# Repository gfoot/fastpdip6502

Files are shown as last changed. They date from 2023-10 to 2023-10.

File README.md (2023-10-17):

# Fast PDIP 6502 project sources

This is my attempt at making a fast 6502-based computer, overclocking the CPU to 32MHz and 
beyond, while retaining a 70s/80s-style parallel architecture, with ISA-style expansion slots,
using only PDIP and through-hole components.

See https://hackaday.io/project/192630-fast-pdip-6502-computer for more details including
photos, schematics, and a more complete description of the development and theory of the
project.

This repository contains:

* hardware/breadboard - schematics and "PCB" layout files for the breadboard prototype
* hardware/pcb - schematics, PCB layouts, gerbers, etc for the all the PCBs
* pld - various PLD module code required by different versions
* server - Python serial server code
* src - 6502 assembler code
* utils - other utility scripts

See also other READMEs:
* [src/README.md](src/README.md)
* [hardware/pcb/README.md](hardware/pcb/README.md)
* [hardware/breadboard/README.md](hardware/breadboard/README.md)

# Building

The hardware files need to be loaded into KiCad 7.0 for editing, exporting gerbers, etc.

The gerber zips can be sent straight to a PCB manufacturer if you just want the same PCBs that
I am using.

The PLD files are built using WinCupl.  I do this from the command line but you can also do it
in the GUI if you prefer.

The 6502 assembler source is built using xa, which is easy to install under Ubuntu at least.  One build
step requires use of Python to create a #include file - I use Python 3 for this.  There's a Makefile in
the "src" directory.

The serial server program is also written in Python, for Python 3.

All of this is run on Ubuntu Linux but you should be able to port it to other systems.

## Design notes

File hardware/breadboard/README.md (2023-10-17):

# Breadboard circuit and layout

This project was used to define a slightly modified circuit for implementation on solderless
breadboards, and to plan the layout of the components.  It combines the CPU and I/O modules, but has
some parts removed which are only relevant to the PCB version such as I/O expansion sockets.

The PCB layout editor shows the positioning of the components on the breadboard, but not the connections between them.

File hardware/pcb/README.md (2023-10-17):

# PCB design files

There are various KiCad projects that together make up the system.  The I/O module and CPU module are required
of course, the others are optional add-ons.

The gerbers for all the revisions I've made ("issues") are also included, along with exported schematics in PDF and PNG files
correspsonding to those revisions for easy reference.

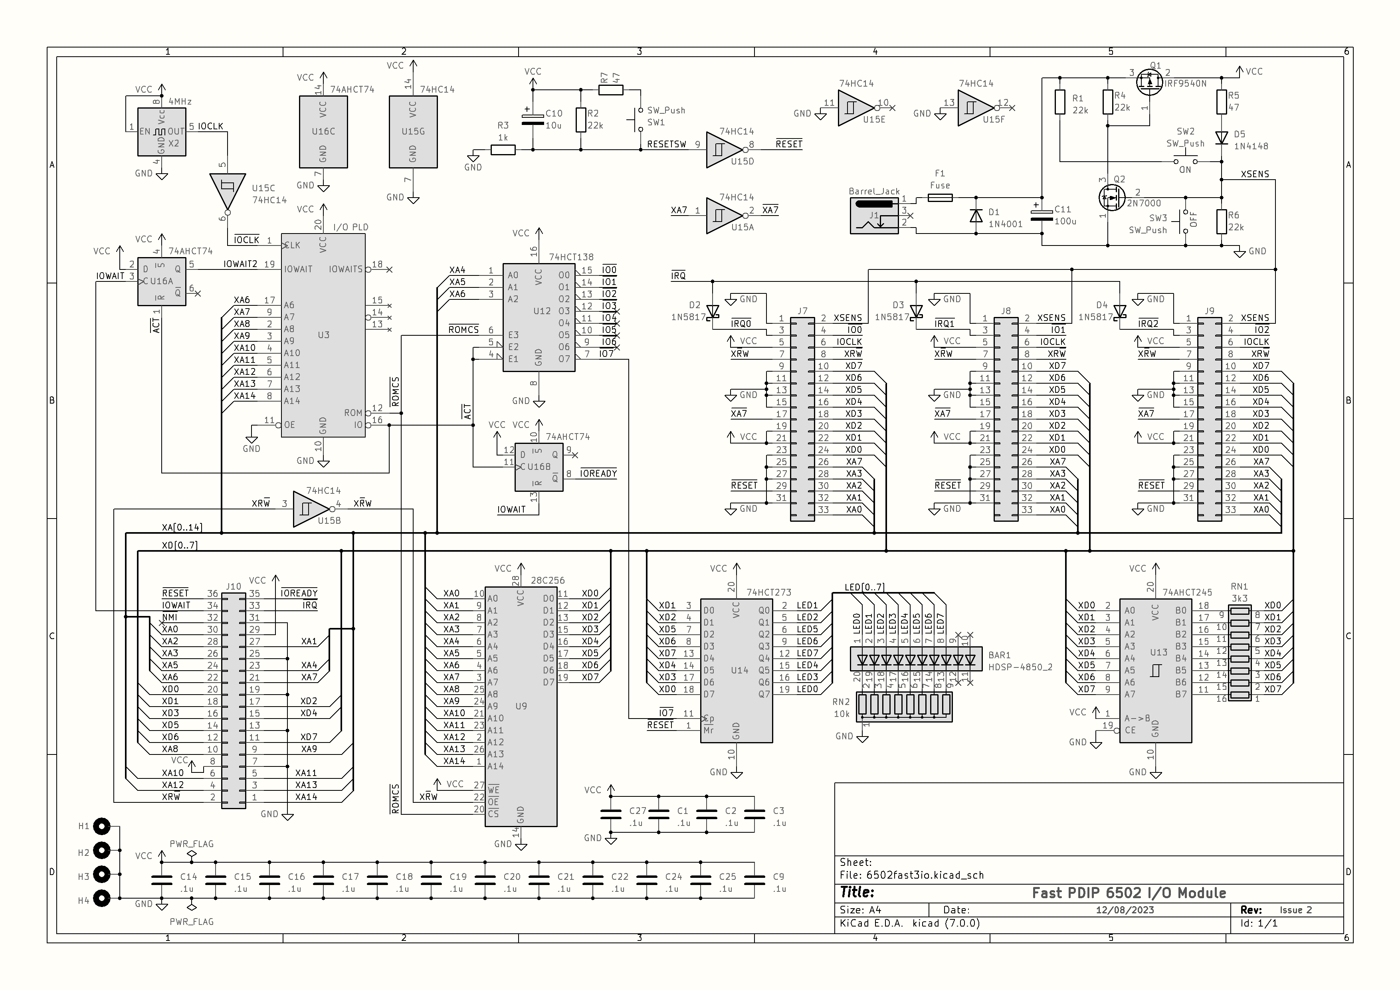
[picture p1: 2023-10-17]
hardware/pcb/schematics/6502fast3io-iss2-schematic.png

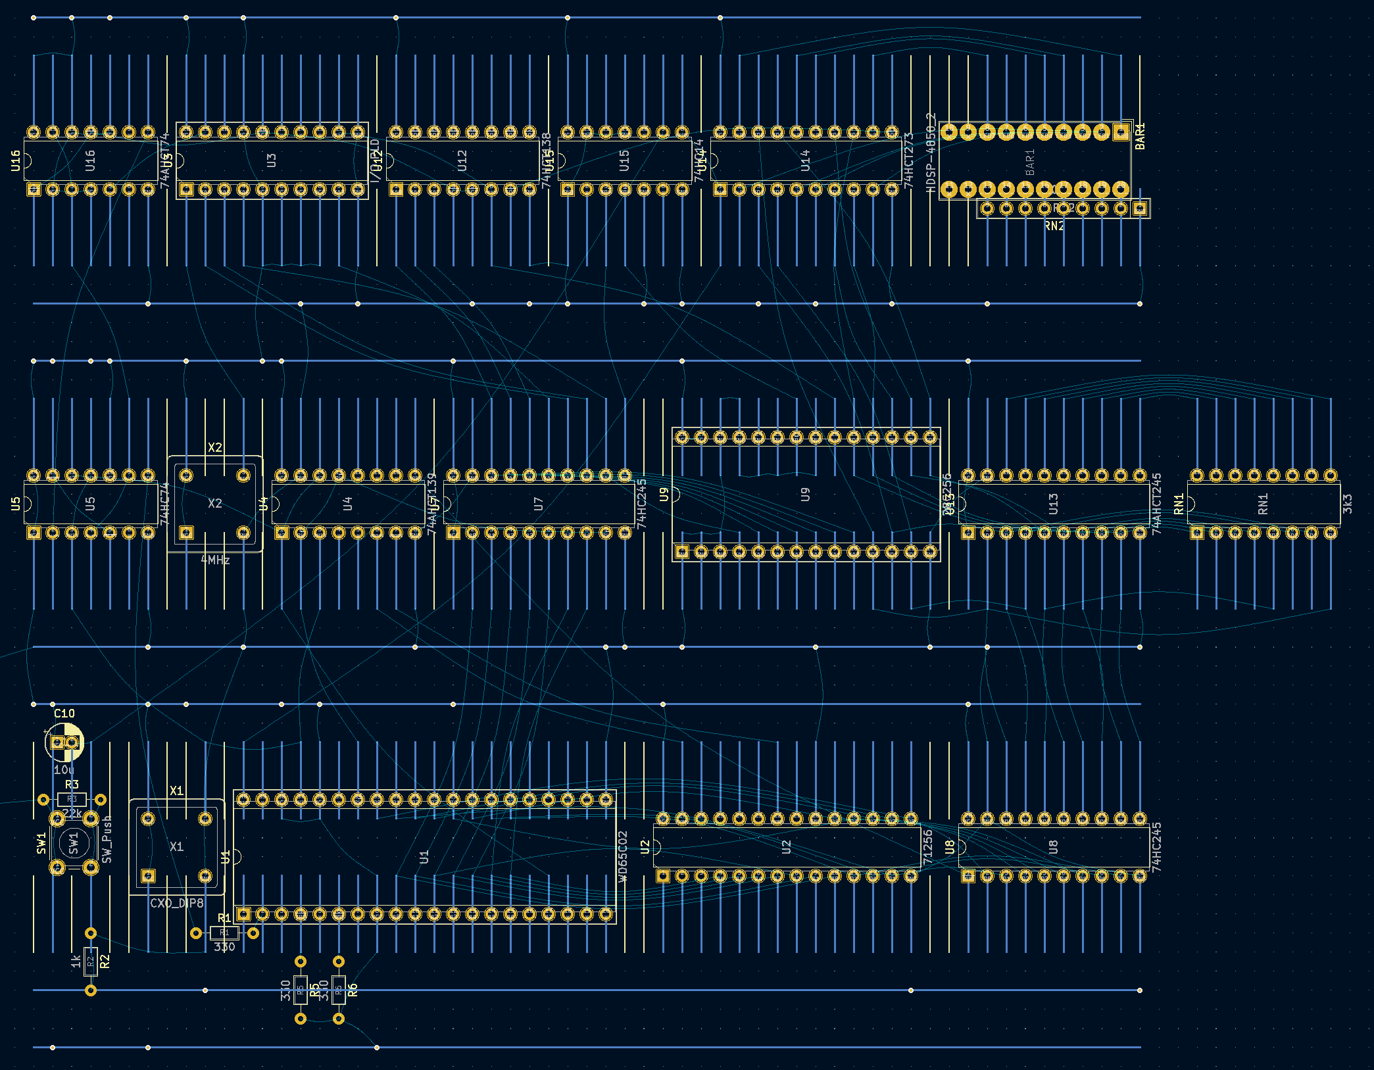
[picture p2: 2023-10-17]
hardware/breadboard/6502fastbb/kicad-breadboard-layout.png

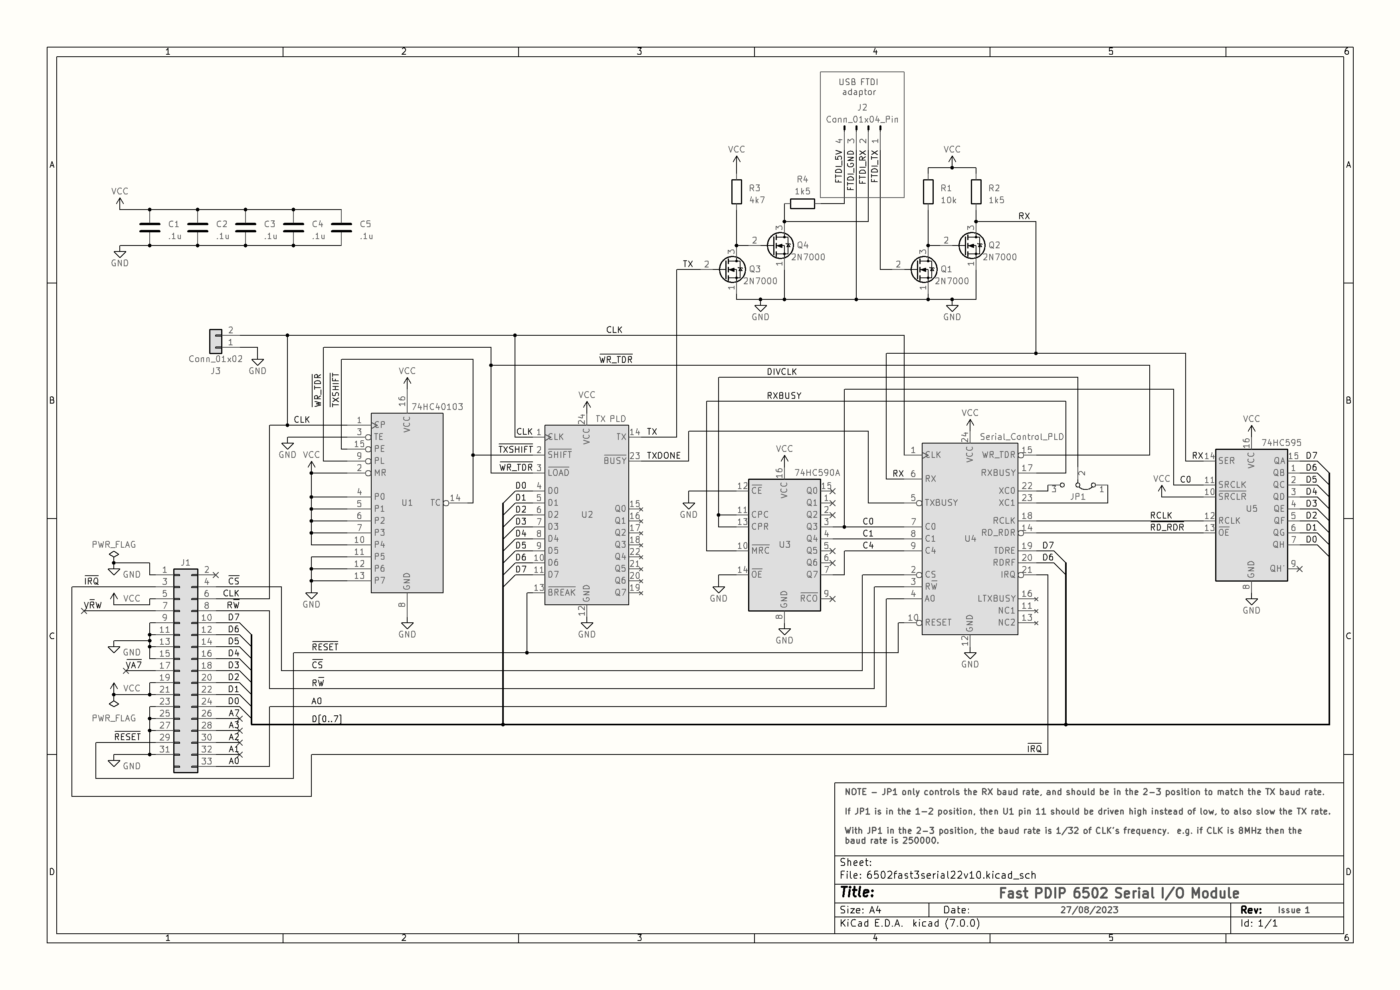
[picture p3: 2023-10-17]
hardware/pcb/schematics/6502fast3serial22v10-iss1-schematic.png

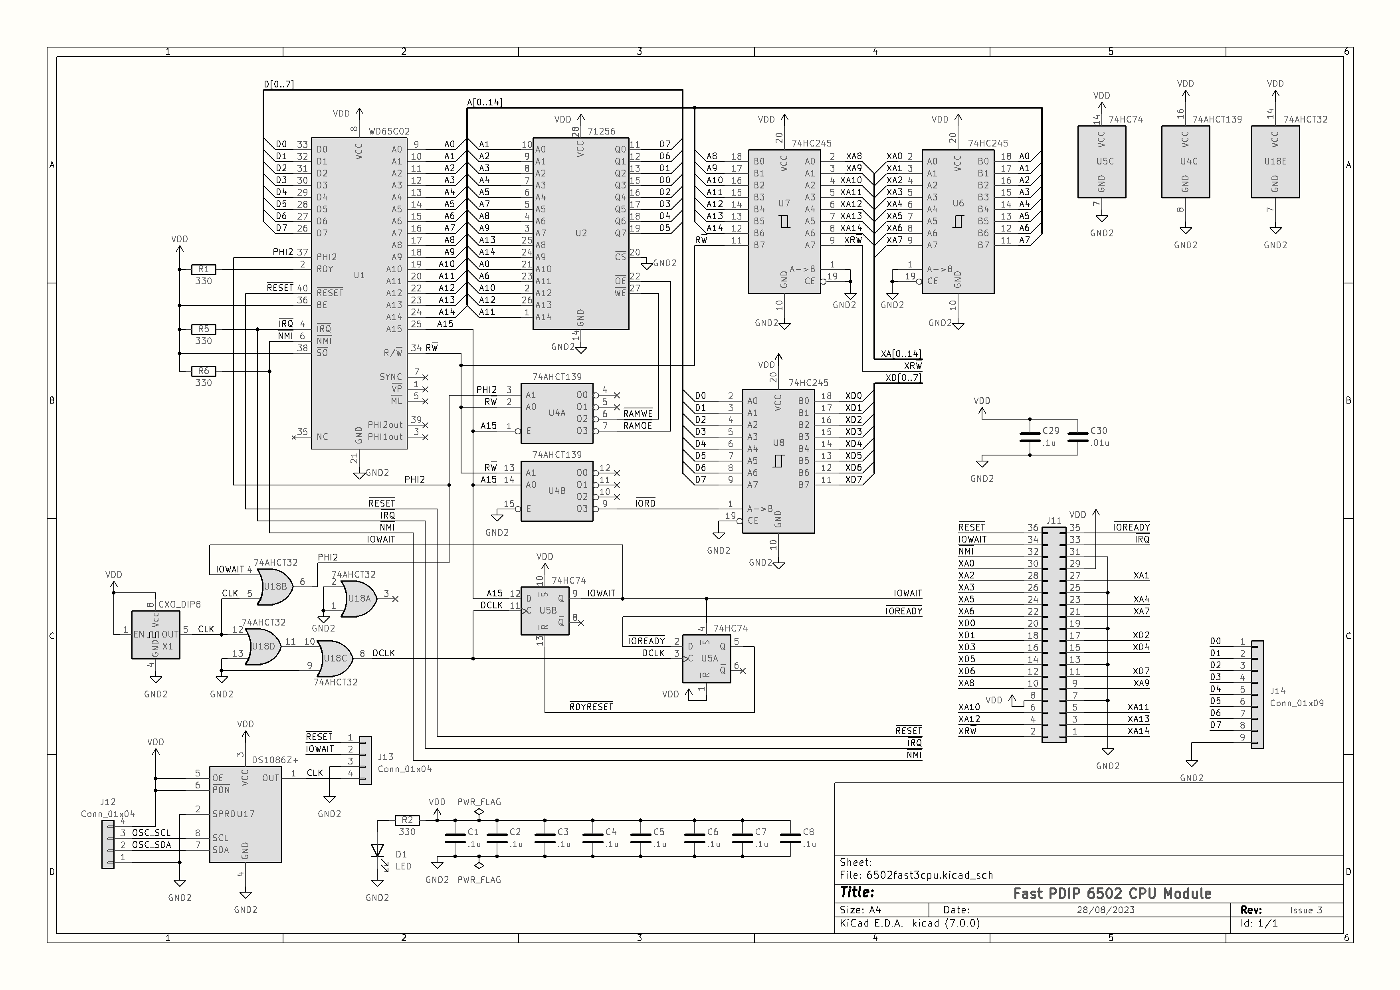
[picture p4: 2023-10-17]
hardware/pcb/schematics/6502fast3cpu-iss3-schematic.png

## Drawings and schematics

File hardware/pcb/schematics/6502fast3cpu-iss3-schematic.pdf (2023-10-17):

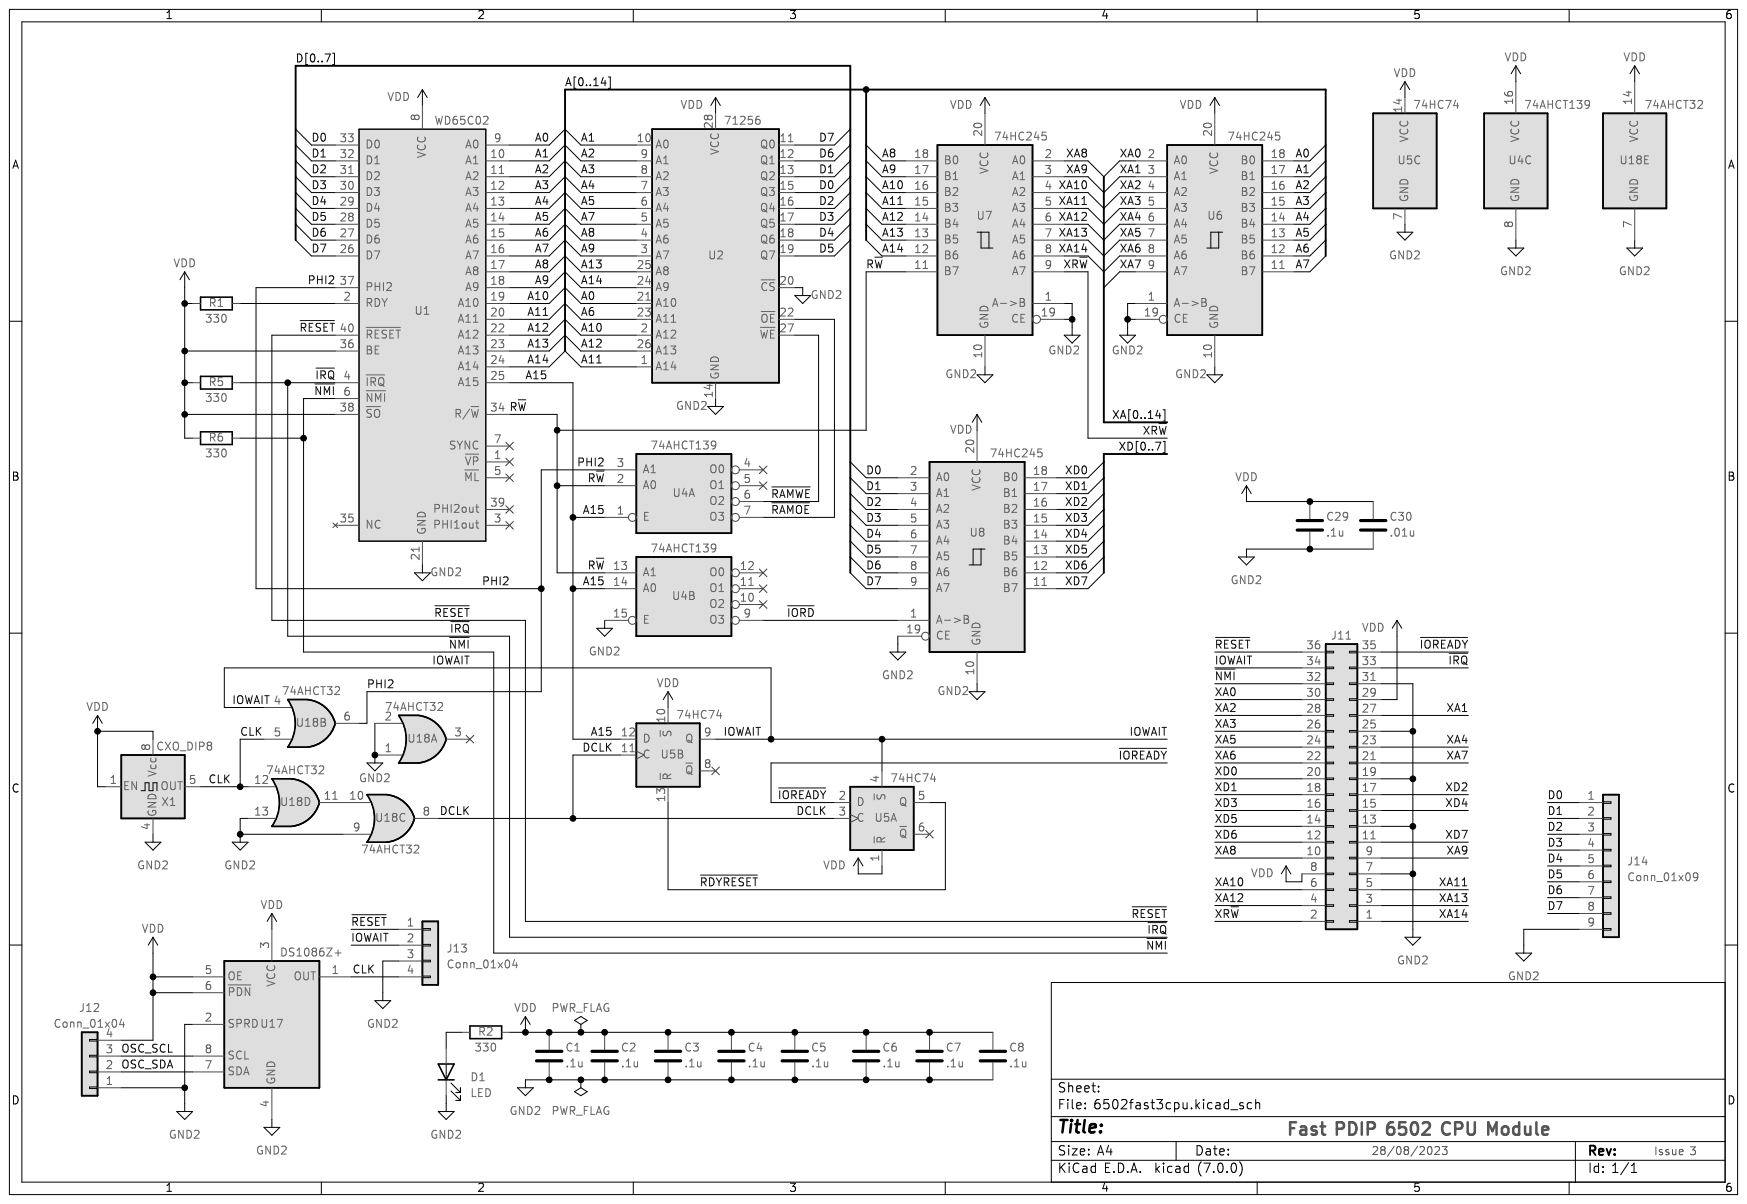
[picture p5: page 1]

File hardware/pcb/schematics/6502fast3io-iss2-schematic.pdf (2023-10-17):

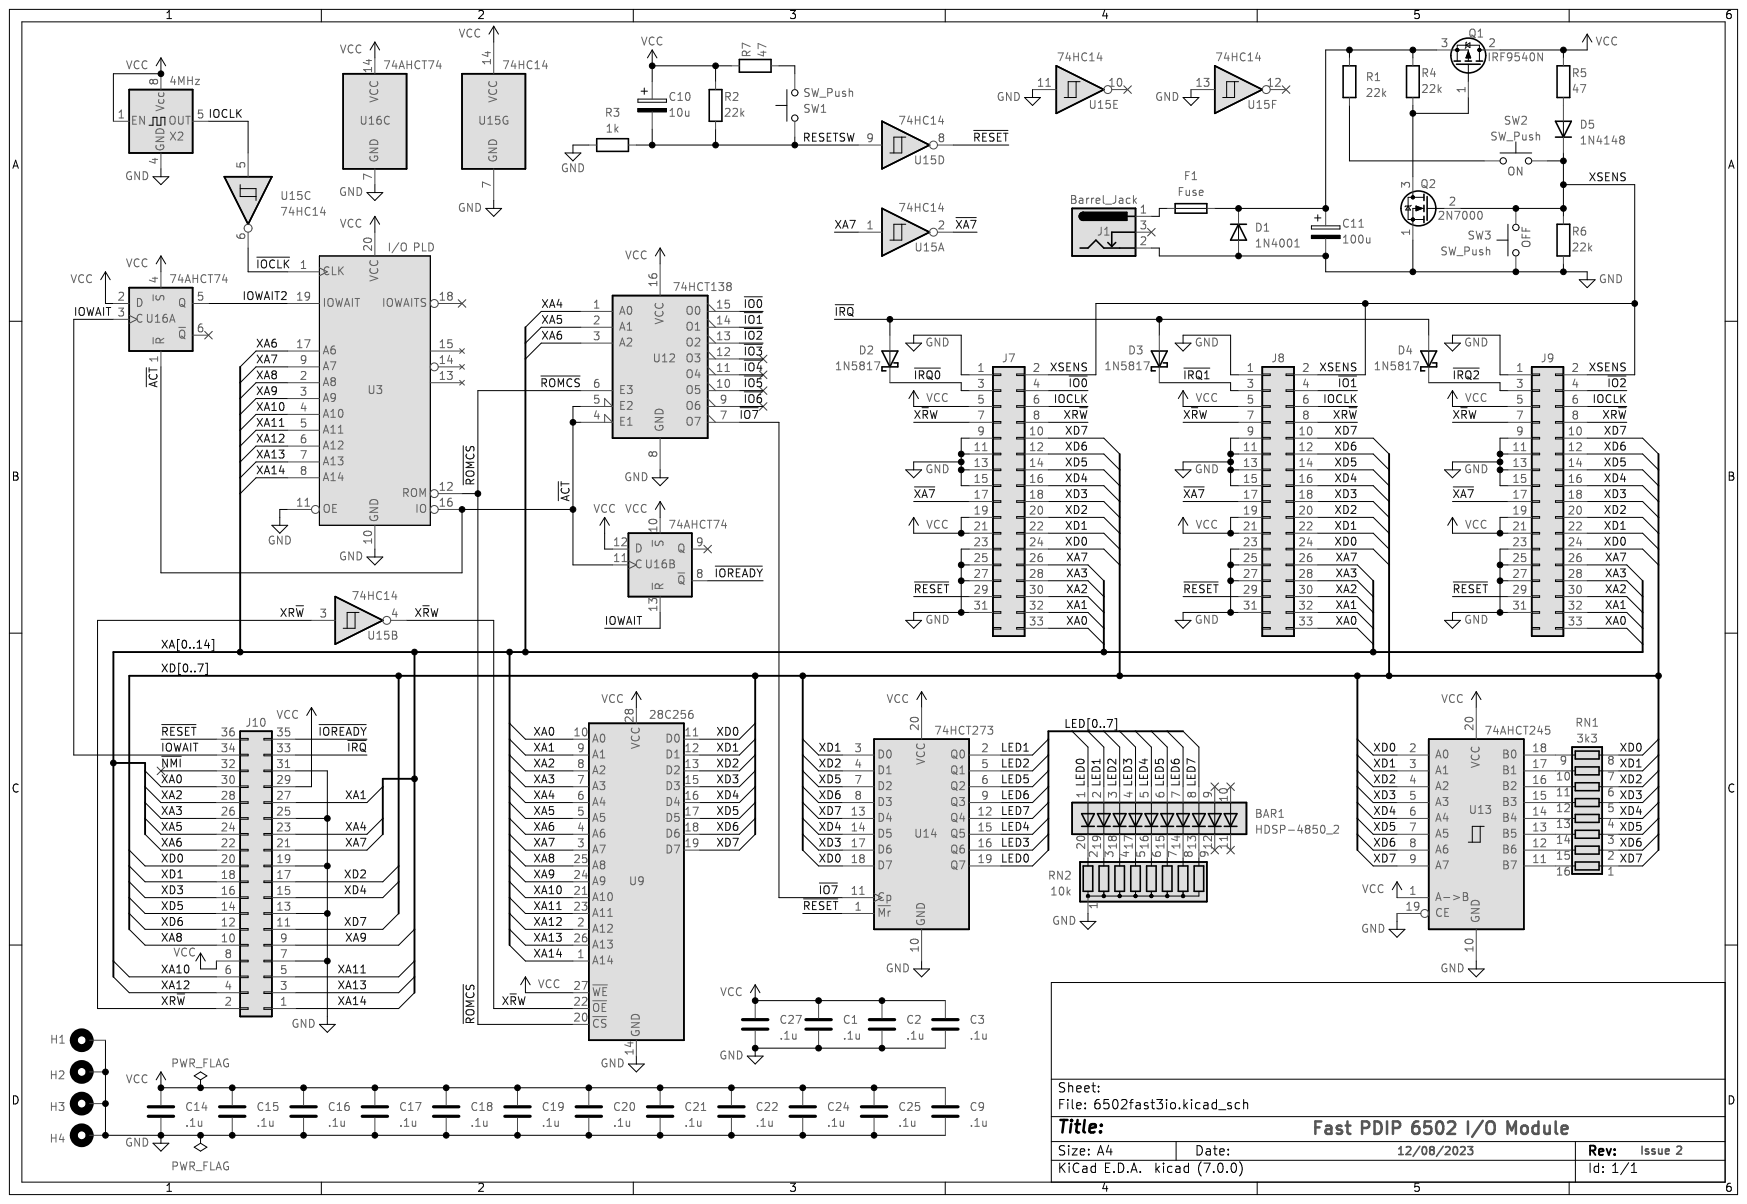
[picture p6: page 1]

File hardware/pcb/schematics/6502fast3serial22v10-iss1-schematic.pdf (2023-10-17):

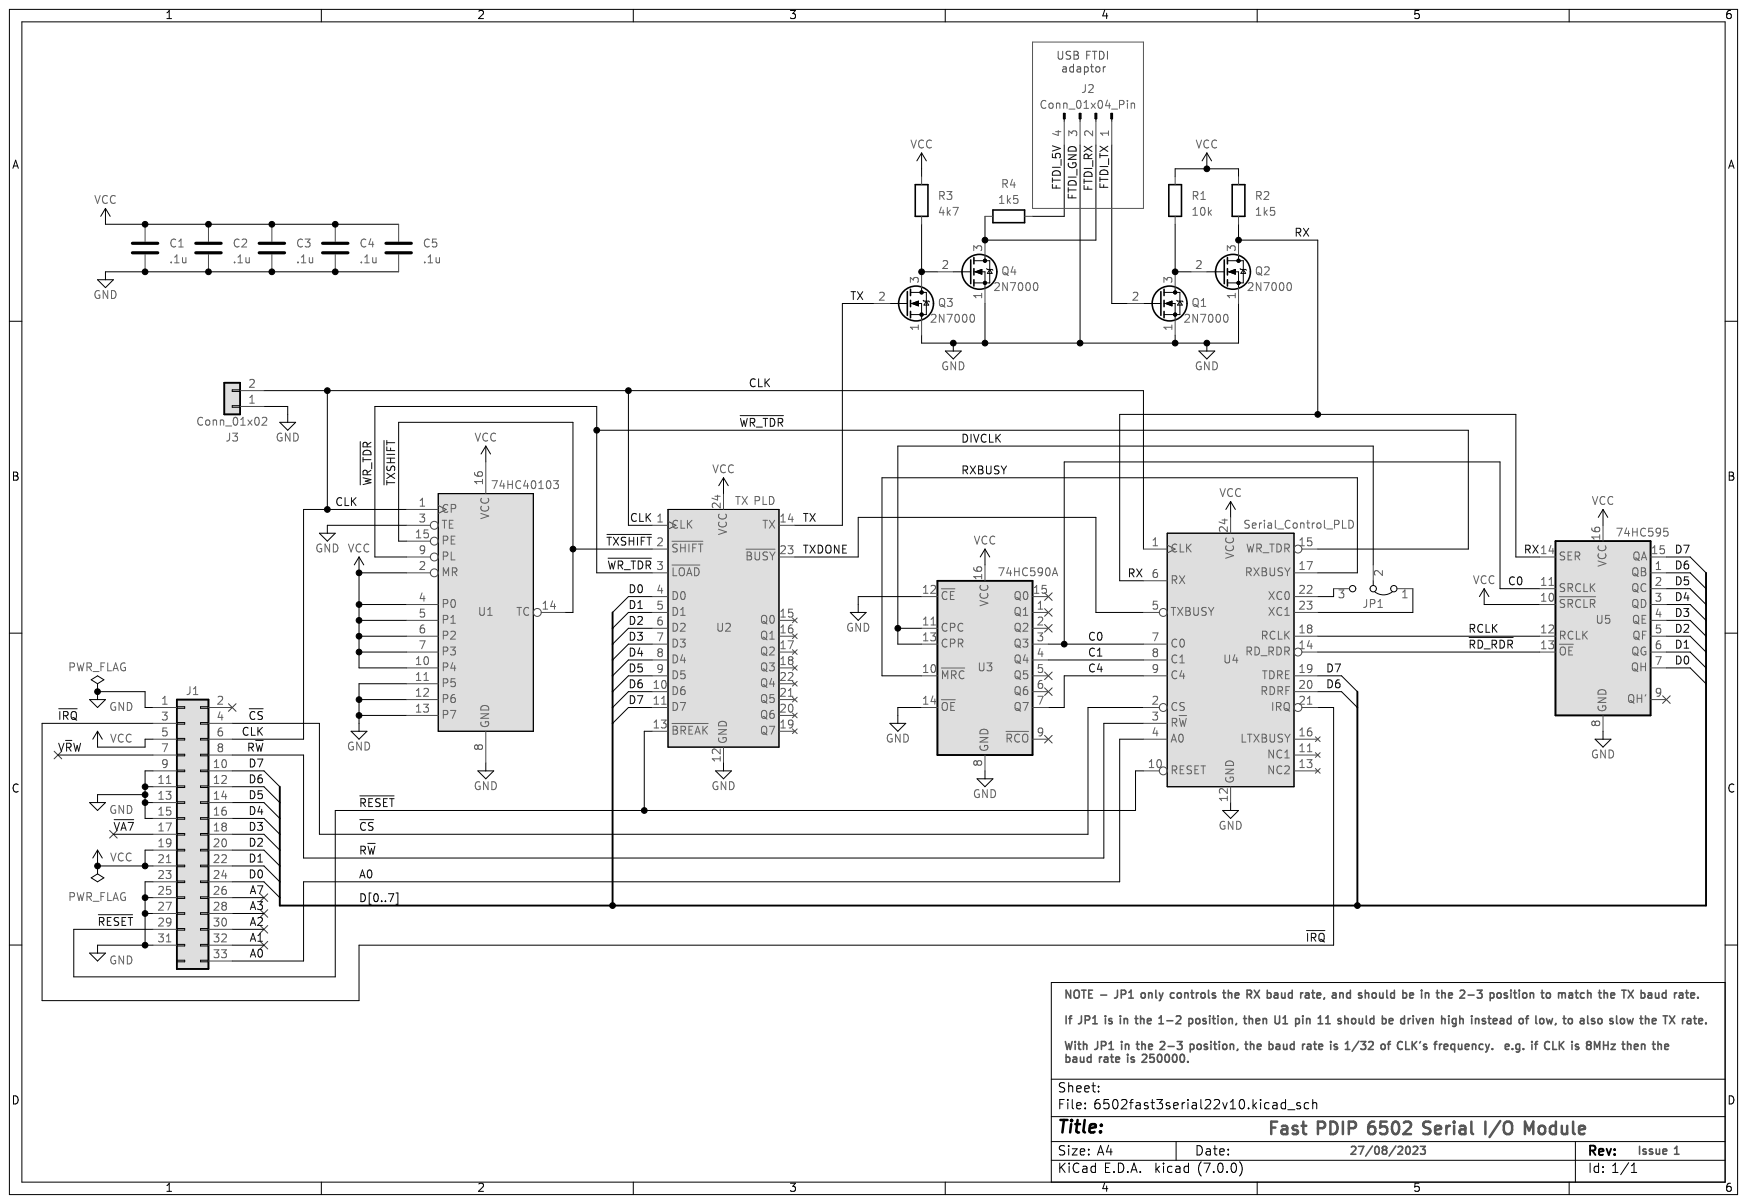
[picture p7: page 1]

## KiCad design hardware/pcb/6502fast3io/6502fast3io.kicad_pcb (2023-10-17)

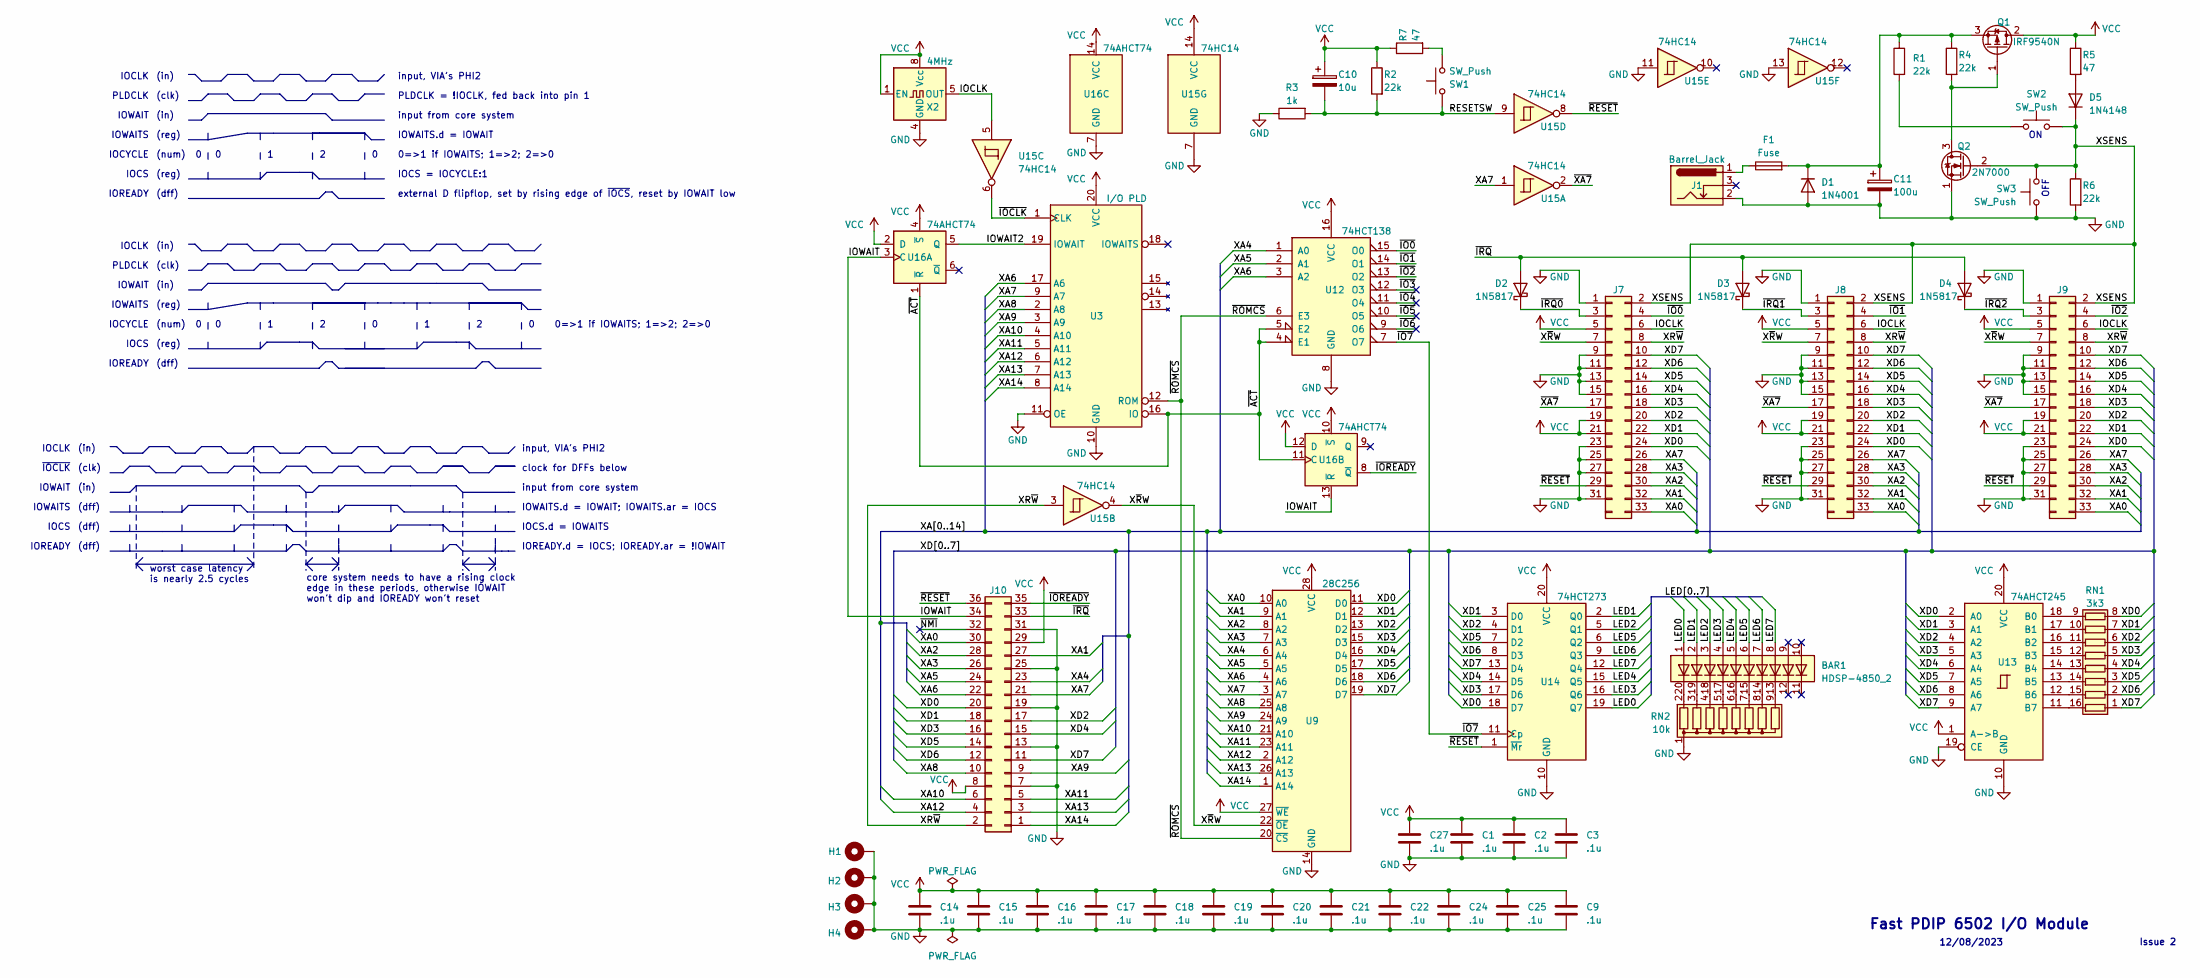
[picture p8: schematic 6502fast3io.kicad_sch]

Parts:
BAR1: HDSP-4850_2; HDSP-4850
C1, C2, C3, C9, C14, C15, C16, C17, C18, C19, C20, C21, C22, C24, C25, C27: .1u; C_Disc_D3.0mm_W1.6mm_P2.50mm
C10: 10u; CP_Radial_D5.0mm_P2.00mm
C11: 100u; CP_Radial_D5.0mm_P2.00mm
D1: 1N4001; D_DO-41_SOD81_P10.16mm_Horizontal
D2, D3, D4: 1N5817; D_DO-34_SOD68_P7.62mm_Horizontal
D5: 1N4148; D_DO-34_SOD68_P10.16mm_Horizontal
F1: Fuse; R_Axial_DIN0207_L6.3mm_D2.5mm_P10.16mm_Horizontal
H1, H2, H3, H4: MountingHole_Pad; MountingHole_2.2mm_M2_Pad
J1: Barrel_Jack; BarrelJack_Horizontal
J7, J8, J9: conn_pcb_edge_33pin_sense; 6502fast2_IO_PCBEdgeSocket
J10: Conn_02x18_Odd_Even; PCB_Edge_Socket_36pin
Q1: IRF9540N; TO-220-3_Horizontal_TabDown_NoHole
Q2: 2N7000; TO-92_Inline
R1, R2, R4, R6: 22k; R_Axial_DIN0204_L3.6mm_D1.6mm_P7.62mm_Horizontal
R3: 1k; R_Axial_DIN0204_L3.6mm_D1.6mm_P7.62mm_Horizontal
R5, R7: 47; R_Axial_DIN0204_L3.6mm_D1.6mm_P7.62mm_Horizontal
RN1: 3k3; DIP-16_W7.62mm
RN2: 10k; R_Array_SIP9
SW1, SW2, SW3: SW_Push; SW_PUSH_6mm_H4.3mm
U3: I/O PLD; DIP-20_W7.62mm_Socket
U9: 28C256; DIP-28_W15.24mm_Socket
U12: 74HCT138; DIP-16_W7.62mm
U13: 74AHCT245; DIP-20_W7.62mm
U14: 74HCT273; DIP-20_W7.62mm
U15: 74HC14; DIP-14_W7.62mm
U16: 74AHCT74; DIP-14_W7.62mm
X2: 4MHz; Oscillator_DIP-8

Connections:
/IOCLK: J7.6, J8.6, J9.6, U15.5, X2.5 (OUT)
/IOWAIT: J10.34, U16.3 (C), U16.13 (~R)
/IOWAIT2: U3.19 (IOWAIT), U16.5 (Q)
/LED0: BAR1.1 (A), U14.19 (Q7)
/LED1: BAR1.2 (A), U14.2 (Q0)
/LED2: BAR1.3 (A), U14.5 (Q1)
/LED3: BAR1.4 (A), U14.16 (Q6)
/LED4: BAR1.5 (A), U14.15 (Q5)
/LED5: BAR1.6 (A), U14.6 (Q2)
/LED6: BAR1.7 (A), U14.9 (Q3)
/LED7: BAR1.8 (A), U14.12 (Q4)
/RESETSW: C10.2, R2.2, R3.2, SW1.2, U15.9
/XA0: J7.33, J8.33, J9.33, J10.30, U9.10 (A0)
/XA1: J7.32, J8.32, J9.32, J10.27, U9.9 (A1)
/XA2: J7.30, J8.30, J9.30, J10.28, U9.8 (A2)
/XA3: J7.28, J8.28, J9.28, J10.26, U9.7 (A3)
/XA4: J10.23, U9.6 (A4), U12.1 (A0)
/XA5: J10.24, U9.5 (A5), U12.2 (A1)
/XA6: J10.22, U3.17 (A6), U9.4 (A6), U12.3 (A2)
/XA7: J7.26, J8.26, J9.26, J10.21, U3.9 (A7), U9.3 (A7), U15.1
/XA8: J10.10, U3.2 (A8), U9.25 (A8)
/XA9: J10.9, U3.3 (A9), U9.24 (A9)
/XA10: J10.6, U3.4 (A10), U9.21 (A10)
/XA11: J10.5, U3.5 (A11), U9.23 (A11)
/XA12: J10.4, U3.6 (A12), U9.2 (A12)
/XA13: J10.3, U3.7 (A13), U9.26 (A13)
/XA14: J10.1, U3.8 (A14), U9.1 (A14)
/XD0: J7.24, J8.24, J9.24, J10.20, RN1.8 (R8.1), U9.11 (D0), U13.2 (A0), U14.18 (D7)
/XD1: J7.22, J8.22, J9.22, J10.18, RN1.7 (R7.1), U9.12 (D1), U13.3 (A1), U14.3 (D0)
/XD2: J7.20, J8.20, J9.20, J10.17, RN1.6 (R6.1), U9.13 (D2), U13.4 (A2), U14.4 (D1)
/XD3: J7.18, J8.18, J9.18, J10.16, RN1.5 (R5.1), U9.15 (D3), U13.5 (A3), U14.17 (D6)
/XD4: J7.16, J8.16, J9.16, J10.15, RN1.4 (R4.1), U9.16 (D4), U13.6 (A4), U14.14 (D5)
/XD5: J7.14, J8.14, J9.14, J10.14, RN1.3 (R3.1), U9.17 (D5), U13.7 (A5), U14.7 (D2)
/XD6: J7.12, J8.12, J9.12, J10.12, RN1.2 (R2.1), U9.18 (D6), U13.8 (A6), U14.8 (D3)
/XD7: J7.10, J8.10, J9.10, J10.11, RN1.1 (R1.1), U9.19 (D7), U13.9 (A7), U14.13 (D4)
/XR~W: J7.8, J8.8, J9.8, J10.2, U15.3
/XSENS: D5.1 (K), J7.2, J8.2, J9.2, Q2.2 (G), R6.1, SW2.2, SW3.2
/X~RW: J7.7, J8.7, J9.7, U9.22 (~OE), U15.4
/~ACT: U3.16 (IO), U12.4 (E1), U12.5 (E2), U16.1 (~R), U16.11 (C)
/~IO0: J7.4, U12.15 (O0)
/~IO1: J8.4, U12.14 (O1)
/~IO2: J9.4, U12.13 (O2)
/~IO3: U12.12 (O3)
/~IO4: U12.11 (O4)
/~IO5: U12.10 (O5)
/~IO6: U12.9 (O6)
/~IO7: U12.7 (O7), U14.11 (Cp)
/~IOCLK: U3.1 (CLK), U15.6
/~IOREADY: J10.35, U16.8 (~Q)
/~IRQ0: D2.1 (K), J7.3
/~IRQ1: D3.1 (K), J8.3
/~IRQ2: D4.1 (K), J9.3
/~IRQ: D2.2 (A), D3.2 (A), D4.2 (A), J10.33
/~NMI: J10.32
/~RESET: J7.29, J8.29, J9.29, J10.36, U14.1 (~Mr), U15.8
/~ROMCS: U3.12 (ROM), U9.20 (~CS), U12.6 (E3)
/~XA7: J7.17, J8.17, J9.17, U15.2
GND: C1.2, C2.2, C3.2, C9.2, C11.2, C14.2, C15.2, C16.2, C17.2, C18.2, C19.2, C20.2, C21.2, C22.2, C24.2, C25.2, C27.2, D1.2 (A), H1.1, H2.1, H3.1, H4.1, J1.2, J7.1, J7.9, J7.11, J7.13, J7.15, J7.23, J7.25, J7.27, J7.31, J8.1, J8.9, J8.11, J8.13, J8.15, J8.23, J8.25, J8.27, J8.31, J9.1, J9.9, J9.11, J9.13, J9.15, J9.23, J9.25, J9.27, J9.31, J10.7, J10.13, J10.19, J10.25, J10.31, Q2.1 (S), R3.1, R6.2, RN2.1 (common), SW3.1, U3.10 (GND), U3.11 (OE), U9.14 (GND), U12.8 (GND), U13.10 (GND), U13.19 (CE), U14.10 (GND), U15.7 (GND), U15.11, U15.13, U16.7 (GND), X2.4 (GND)
unnamed: C11.1, D1.1 (K), F1.2, Q1.3 (S), R1.1, R4.1
unnamed: D5.2 (A), R5.2
unnamed: F1.1, J1.1
unnamed: Q1.1 (G), Q2.3 (D), R4.2
unnamed: R1.2, SW2.1
unnamed: R7.2, SW1.1
unnamed: RN1.16 (R1.2), U13.11 (B7)
unnamed: RN1.15 (R2.2), U13.12 (B6)
unnamed: RN1.14 (R3.2), U13.13 (B5)
unnamed: RN1.13 (R4.2), U13.14 (B4)
unnamed: RN1.12 (R5.2), U13.15 (B3)
unnamed: RN1.11 (R6.2), U13.16 (B2)
unnamed: RN1.10 (R7.2), U13.17 (B1)
unnamed: RN1.9 (R8.2), U13.18 (B0)
unnamed: BAR1.20 (K), RN2.2 (R1)
unnamed: BAR1.19 (K), RN2.3 (R2)
unnamed: BAR1.18 (K), RN2.4 (R3)
unnamed: BAR1.17 (K), RN2.5 (R4)
unnamed: BAR1.16 (K), RN2.6 (R5)
unnamed: BAR1.15 (K), RN2.7 (R6)
unnamed: BAR1.14 (K), RN2.8 (R7)
unnamed: BAR1.13 (K), RN2.9 (R8)
VCC: C1.1, C2.1, C3.1, C9.1, C10.1, C14.1, C15.1, C16.1, C17.1, C18.1, C19.1, C20.1, C21.1, C22.1, C24.1, C25.1, C27.1, J7.5, J7.19, J7.21, J8.5, J8.19, J8.21, J9.5, J9.19, J9.21, J10.8, J10.29, Q1.2 (D), R2.1, R5.1, R7.1, U3.20 (VCC), U9.27 (~WE), U9.28 (VCC), U12.16 (VCC), U13.1 (A->B), U13.20 (VCC), U14.20 (VCC), U15.14 (VCC), U16.2 (D), U16.4 (~S), U16.10 (~S), U16.12 (D), U16.14 (VCC), X2.1 (EN), X2.8 (Vcc)

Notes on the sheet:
(num)
IOCLK
OFF
12/08/2023
(dff)
IOCYCLE
IOCS.d = IOWAITS
input from core system
IOREADY
(in)
IOWAITS
IOWAIT
IOWAITS.d = IOWAIT
IOCS
(clk)
external D flipflop, set by rising edge of ~{IOCS}, reset by IOWAIT low
PLDCLK = !IOCLK, fed back into pin 1
worst case latency is nearly 2.5 cycles
core system needs to have a rising clock edge in these periods, otherwise IOWAIT won't dip and IOREADY won't reset
clock for DFFs below
(reg)
IOREADY.d = IOCS; IOREADY.ar = !IOWAIT
Issue 2
0=>1 if IOWAITS; 1=>2; 2=>0
PLDCLK
IOCS = IOCYCLE:1
Fast PDIP 6502 I/O Module
input, VIA's PHI2
~{IOCLK}
IOWAITS.d = IOWAIT; IOWAITS.ar = IOCS

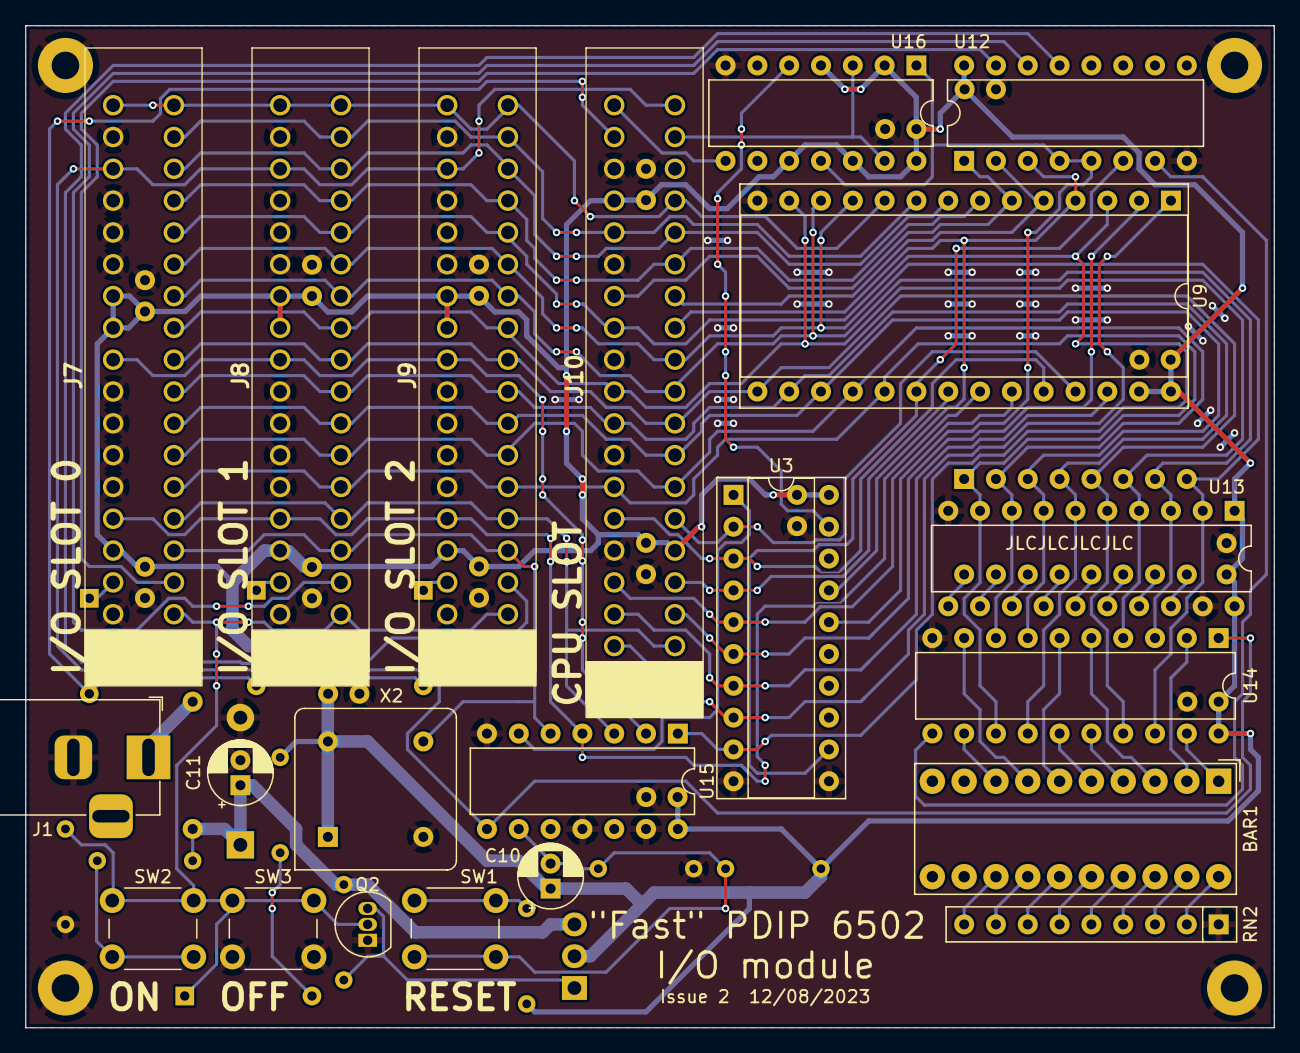
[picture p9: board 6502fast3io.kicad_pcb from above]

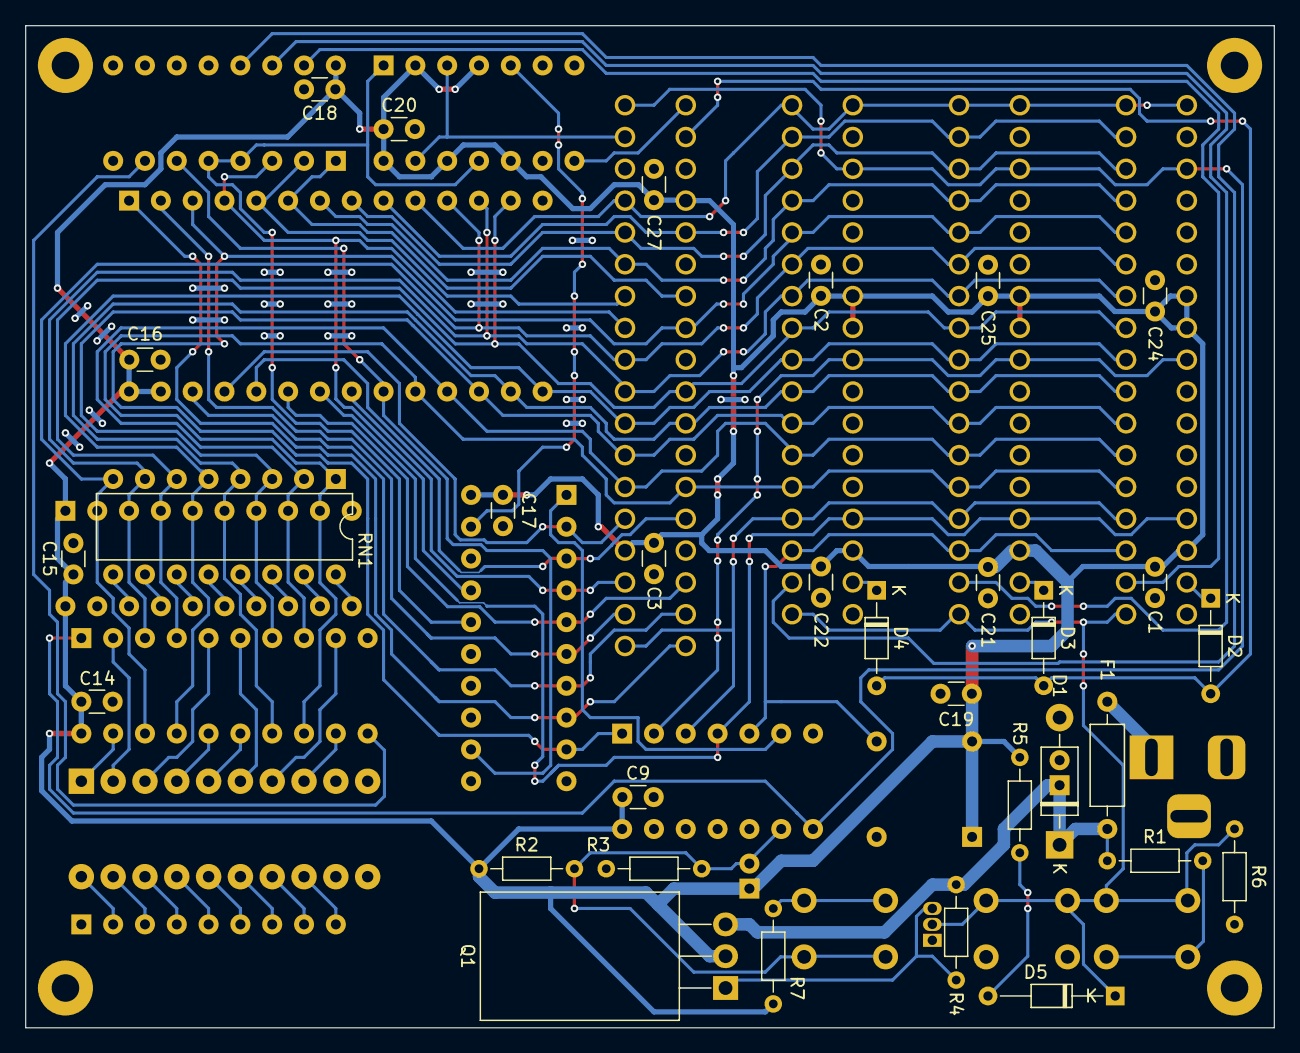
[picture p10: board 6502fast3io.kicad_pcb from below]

Board: 2 copper layers, 99.7 x 80.0 mm, 56 parts (31 on the bottom side), 76 nets.

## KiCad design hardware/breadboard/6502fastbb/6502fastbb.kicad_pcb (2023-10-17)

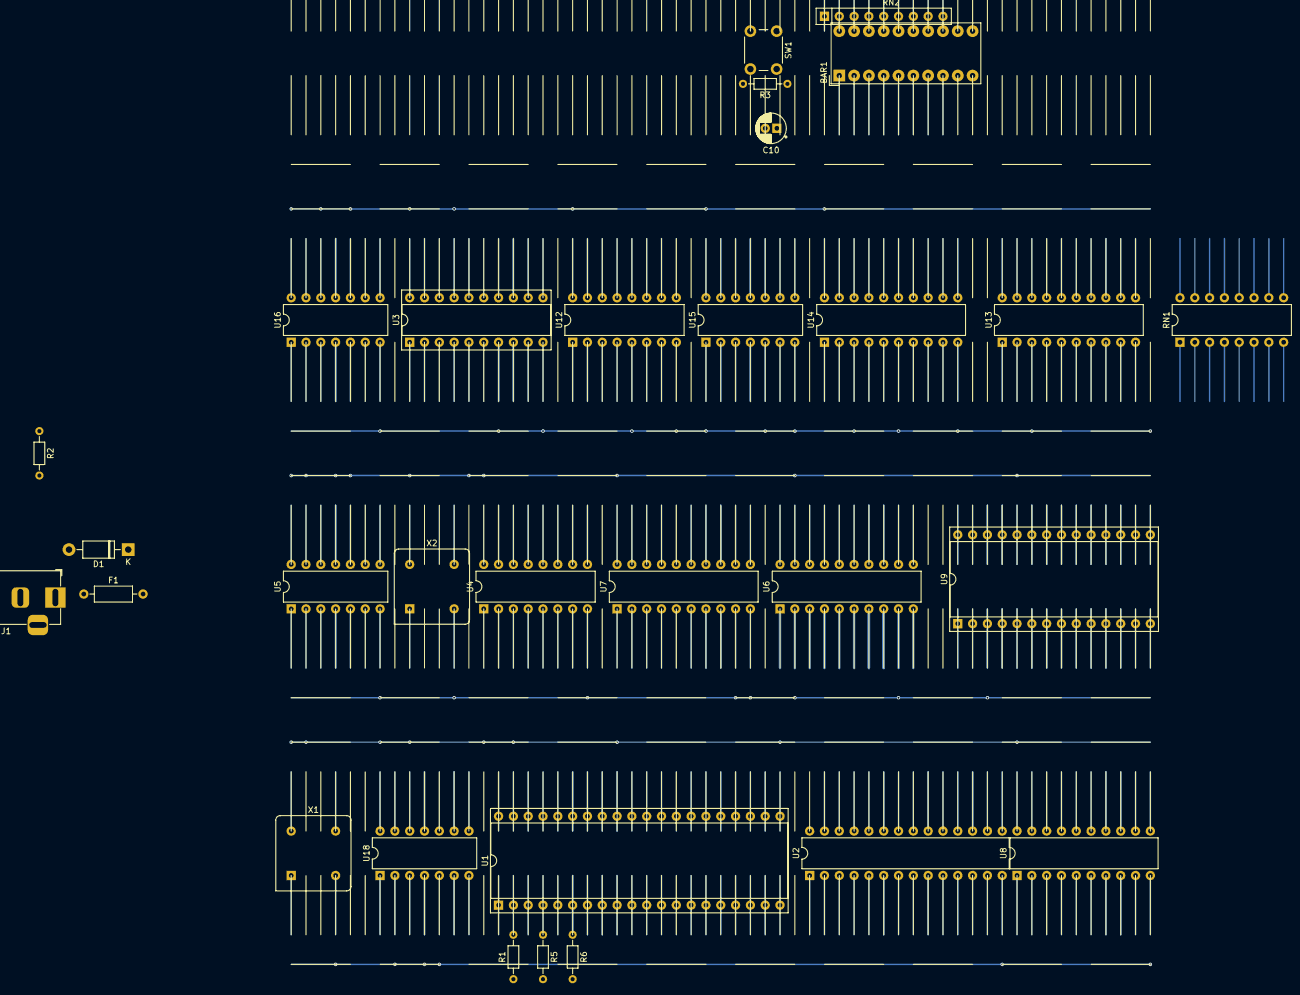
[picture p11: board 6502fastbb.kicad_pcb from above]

Board: 2 copper layers, 30 parts (0 on the bottom side), 98 nets.

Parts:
BAR1: HDSP-4850_2; HDSP-4850
C10: 10u; CP_Radial_D5.0mm_P2.00mm
D1: 1N4001; D_DO-41_SOD81_P10.16mm_Horizontal
F1: Fuse; R_Axial_DIN0207_L6.3mm_D2.5mm_P10.16mm_Horizontal
J1: Barrel_Jack; BarrelJack_Horizontal
R1: 3k3; R_Axial_DIN0204_L3.6mm_D1.6mm_P7.62mm_Horizontal
R2: 1k; R_Axial_DIN0204_L3.6mm_D1.6mm_P7.62mm_Horizontal
R3: 22k; R_Axial_DIN0204_L3.6mm_D1.6mm_P7.62mm_Horizontal
R5, R6: 330; R_Axial_DIN0204_L3.6mm_D1.6mm_P7.62mm_Horizontal
RN1: 3k3; DIP-16_W7.62mm
RN2: 10k; R_Array_SIP9
SW1: SW_Push; SW_PUSH_6mm_H4.3mm
U1: WD65C02; DIP-40_W15.24mm_Socket
U2: 71256; DIP-28_W7.62mm
U3: I/O PLD; DIP-20_W7.62mm_Socket
U4: 74AHCT139; DIP-16_W7.62mm
U5: 74HC74; DIP-14_W7.62mm
U6, U7, U8: 74HC245; DIP-20_W7.62mm
U9: 28C256; DIP-28_W15.24mm_Socket
U12: 74HCT138; DIP-16_W7.62mm
U13: 74AHCT245; DIP-20_W7.62mm
U14: 74HCT273; DIP-20_W7.62mm
U15: 74HC14; DIP-14_W7.62mm
U16: 74AHCT74; DIP-14_W7.62mm
U18: 74LS32; DIP-14_W7.62mm
X1: CXO_DIP8; Oscillator_DIP-8
X2: 4MHz; Oscillator_DIP-8

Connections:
/A0: U1.9 (A0), U2.1 (A14), U7.2 (A0)
/A1: U1.10 (A1), U2.2 (A12), U7.3 (A1)
/A2: U1.11 (A2), U2.3 (A7), U7.4 (A2)
/A3: U1.12 (A3), U2.4 (A6), U7.5 (A3)
/A4: U1.13 (A4), U2.5 (A5), U7.6 (A4)
/A5: U1.14 (A5), U2.6 (A4), U7.7 (A5)
/A6: U1.15 (A6), U2.7 (A3), U7.8 (A6)
/A7: U1.16 (A7), U2.21 (A10), U6.2 (A0)
/A8: U1.17 (A8), U2.8 (A2), U6.3 (A1)
/A9: U1.18 (A9), U2.9 (A1), U6.4 (A2)
/A10: U1.19 (A10), U2.10 (A0), U6.5 (A3)
/A11: U1.20 (A11), U2.23 (A11), U6.6 (A4)
/A12: U1.22 (A12), U2.24 (A9), U6.7 (A5)
/A13: U1.23 (A13), U2.25 (A8), U6.8 (A6)
/A14: U1.24 (A14), U2.26 (A13), U6.9 (A7)
/A15: U1.25 (A15), U4.1 (E), U4.14 (A0), U5.12 (D)
/CLK: U18.9, U18.12, X1.5 (OUT)
/D0: U1.33 (D0), U2.15 (Q3), U8.2 (A0)
/D1: U1.32 (D1), U2.13 (Q2), U8.3 (A1)
/D2: U1.31 (D2), U2.16 (Q4), U8.4 (A2)
/D3: U1.30 (D3), U2.17 (Q5), U8.5 (A3)
/D4: U1.29 (D4), U2.18 (Q6), U8.6 (A4)
/D5: U1.28 (D5), U2.19 (Q7), U8.7 (A5)
/D6: U1.27 (D6), U2.12 (Q1), U8.8 (A6)
/D7: U1.26 (D7), U2.11 (Q0), U8.9 (A7)
/DCLK: U5.3 (C), U5.11 (C), U18.3
/IO module/IOWAIT2: U3.19 (IOWAIT), U16.5 (Q)
/IO module/LED0: BAR1.1 (A), U14.19 (Q7)
/IO module/LED1: BAR1.2 (A), U14.2 (Q0)
/IO module/LED2: BAR1.3 (A), U14.5 (Q1)
/IO module/LED3: BAR1.4 (A), U14.16 (Q6)
/IO module/LED4: BAR1.5 (A), U14.15 (Q5)
/IO module/LED5: BAR1.6 (A), U14.6 (Q2)
/IO module/LED6: BAR1.7 (A), U14.9 (Q3)
/IO module/LED7: BAR1.8 (A), U14.12 (Q4)
/IO module/RESETSW: C10.2, R2.2, R3.2, SW1.2, U15.9
/IO module/X~RW: U9.22 (~OE), U15.4
/IO module/~ACT: U3.16 (IO), U12.4 (E1), U12.5 (E2), U16.1 (~R), U16.11 (C)
/IO module/~IO7: U12.7 (O7), U14.11 (Cp)
/IO module/~IOCLK: U3.1 (CLK), X2.5 (OUT)
/IO module/~ROMCS: U3.12 (ROM), U9.20 (~CS), U12.6 (E3)
/IOWAIT: U5.4 (~S), U5.9 (Q), U16.3 (C), U16.13 (~R)
/PHI2: U1.37 (PHI2), U4.3 (A1), U18.8
/R~W: U1.34 (R/~W), U4.2 (A0), U4.13 (A1), U7.9 (A7)
/XA0: U7.18 (B0), U9.10 (A0)
/XA1: U7.17 (B1), U9.9 (A1)
/XA2: U7.16 (B2), U9.8 (A2)
/XA3: U7.15 (B3), U9.7 (A3)
/XA4: U7.14 (B4), U9.6 (A4), U12.1 (A0)
/XA5: U7.13 (B5), U9.5 (A5), U12.2 (A1)
/XA6: U3.17 (A6), U7.12 (B6), U9.4 (A6), U12.3 (A2)
/XA7: U3.9 (A7), U6.18 (B0), U9.3 (A7)
/XA8: U3.2 (A8), U6.17 (B1), U9.25 (A8)
/XA9: U3.3 (A9), U6.16 (B2), U9.24 (A9)
/XA10: U3.4 (A10), U6.15 (B3), U9.21 (A10)
/XA11: U3.5 (A11), U6.14 (B4), U9.23 (A11)
/XA12: U3.6 (A12), U6.13 (B5), U9.2 (A12)
/XA13: U3.7 (A13), U6.12 (B6), U9.26 (A13)
/XA14: U3.8 (A14), U6.11 (B7), U9.1 (A14)
/XD0: RN1.8 (R8.1), U8.18 (B0), U9.11 (D0), U13.2 (A0), U14.18 (D7)
/XD1: RN1.7 (R7.1), U8.17 (B1), U9.12 (D1), U13.3 (A1), U14.3 (D0)
/XD2: RN1.6 (R6.1), U8.16 (B2), U9.13 (D2), U13.4 (A2), U14.4 (D1)
/XD3: RN1.5 (R5.1), U8.15 (B3), U9.15 (D3), U13.5 (A3), U14.17 (D6)
/XD4: RN1.4 (R4.1), U8.14 (B4), U9.16 (D4), U13.6 (A4), U14.14 (D5)
/XD5: RN1.3 (R3.1), U8.13 (B5), U9.17 (D5), U13.7 (A5), U14.7 (D2)
/XD6: RN1.2 (R2.1), U8.12 (B6), U9.18 (D6), U13.8 (A6), U14.8 (D3)
/XD7: RN1.1 (R1.1), U8.11 (B7), U9.19 (D7), U13.9 (A7), U14.13 (D4)
/XR~W: U7.11 (B7), U15.3
/~IORD: U4.9 (O3), U8.1 (A->B)
/~IOREADY: U5.2 (D), U16.8 (~Q)
/~IOWAIT: U5.8 (~Q), U18.10
/~IRQ: R5.1, U1.4 (~IRQ)
/~NMI: R6.1, U1.6 (~NMI)
/~RAMOE: U2.22 (~OE), U4.7 (O3)
/~RAMWE: U2.27 (~WE), U4.6 (O2)
/~RDYRESET: U5.5 (Q), U5.13 (~R)
/~RESET: U1.40 (~RESET), U14.1 (~Mr), U15.8
GND: D1.2 (A), J1.2, R2.1, RN2.1 (common), U1.21 (GND), U2.14 (GND), U2.20 (~CS), U3.10 (GND), U3.11 (OE), U4.8 (GND), U4.15 (E), U5.7 (GND), U6.10 (GND), U6.19 (CE), U7.10 (GND), U7.19 (CE), U8.10 (GND), U8.19 (CE), U9.14 (GND), U12.8 (GND), U13.10 (GND), U13.19 (CE), U14.10 (GND), U15.1, U15.5, U15.7 (GND), U15.11, U15.13, U16.7 (GND), U18.2, U18.4, U18.5, U18.7 (GND), U18.13, X1.4 (GND), X2.4 (GND)
unnamed: F1.1, J1.1
unnamed: RN1.16 (R1.2), U13.11 (B7)
unnamed: RN1.15 (R2.2), U13.12 (B6)
unnamed: RN1.14 (R3.2), U13.13 (B5)
unnamed: RN1.13 (R4.2), U13.14 (B4)
unnamed: RN1.12 (R5.2), U13.15 (B3)
unnamed: RN1.11 (R6.2), U13.16 (B2)
unnamed: RN1.10 (R7.2), U13.17 (B1)
unnamed: RN1.9 (R8.2), U13.18 (B0)
unnamed: BAR1.20 (K), RN2.2 (R1)
unnamed: BAR1.19 (K), RN2.3 (R2)
unnamed: BAR1.18 (K), RN2.4 (R3)
unnamed: BAR1.17 (K), RN2.5 (R4)
unnamed: BAR1.16 (K), RN2.6 (R5)
unnamed: BAR1.15 (K), RN2.7 (R6)
unnamed: BAR1.14 (K), RN2.8 (R7)
unnamed: BAR1.13 (K), RN2.9 (R8)
unnamed: R1.2, U1.2 (RDY)
unnamed: U18.1, U18.11
VCC: C10.1, D1.1 (K), F1.2, R1.1, R3.1, R5.2, R6.2, SW1.1, U1.8 (VCC), U1.36 (BE), U1.38 (~SO), U2.28 (VCC), U3.20 (VCC), U4.16 (VCC), U5.1 (~R), U5.10 (~S), U5.14 (VCC), U6.1 (A->B), U6.20 (VCC), U7.1 (A->B), U7.20 (VCC), U8.20 (VCC), U9.27 (~WE), U9.28 (VCC), U12.16 (VCC), U13.1 (A->B), U13.20 (VCC), U14.20 (VCC), U15.14 (VCC), U16.2 (D), U16.4 (~S), U16.10 (~S), U16.12 (D), U16.14 (VCC), U18.14 (VCC), X1.1 (EN), X1.8 (Vcc), X2.1 (EN), X2.8 (Vcc)

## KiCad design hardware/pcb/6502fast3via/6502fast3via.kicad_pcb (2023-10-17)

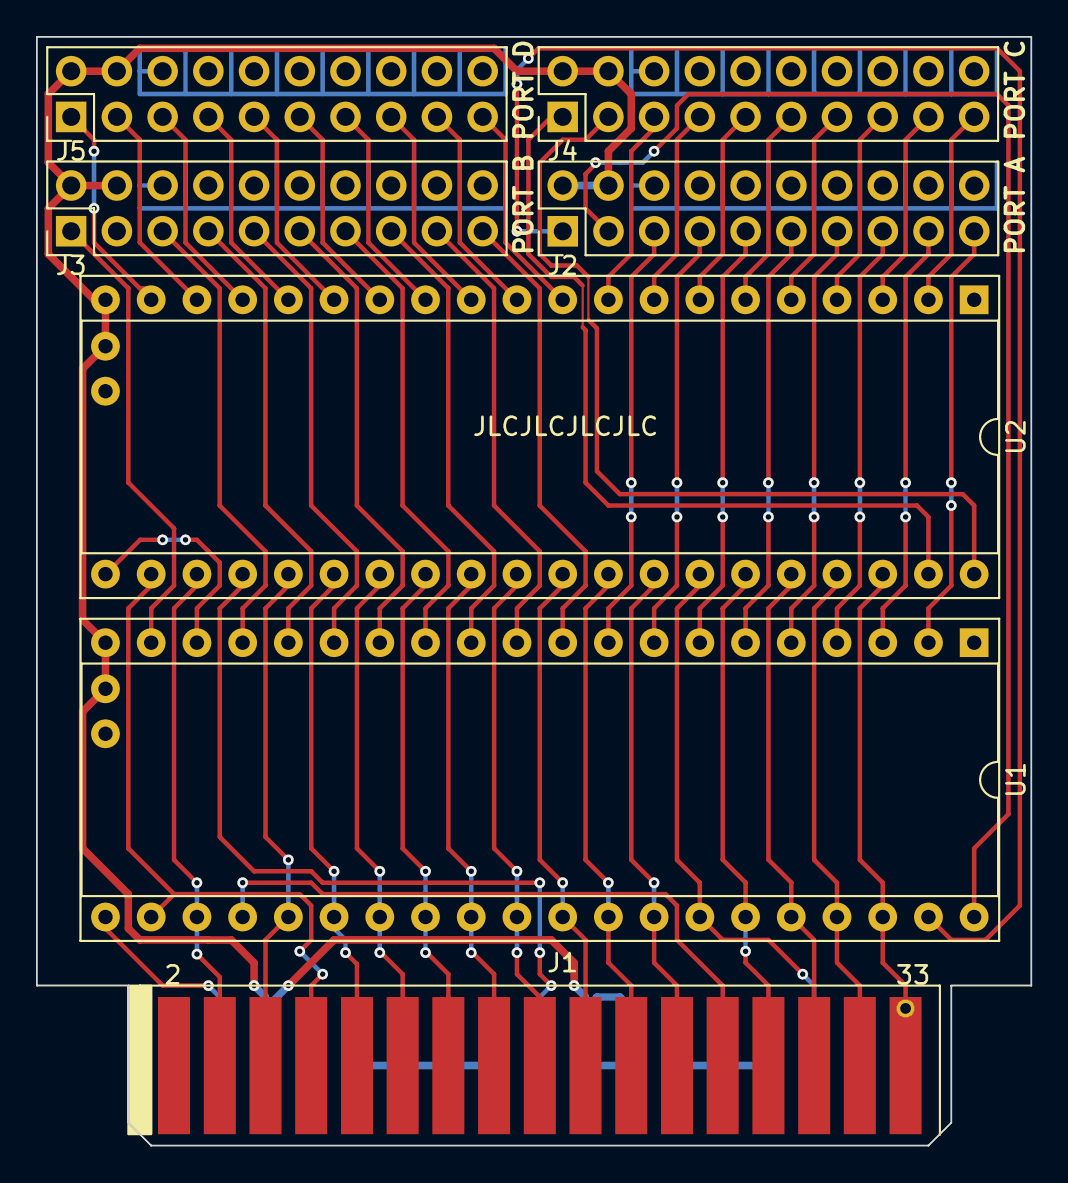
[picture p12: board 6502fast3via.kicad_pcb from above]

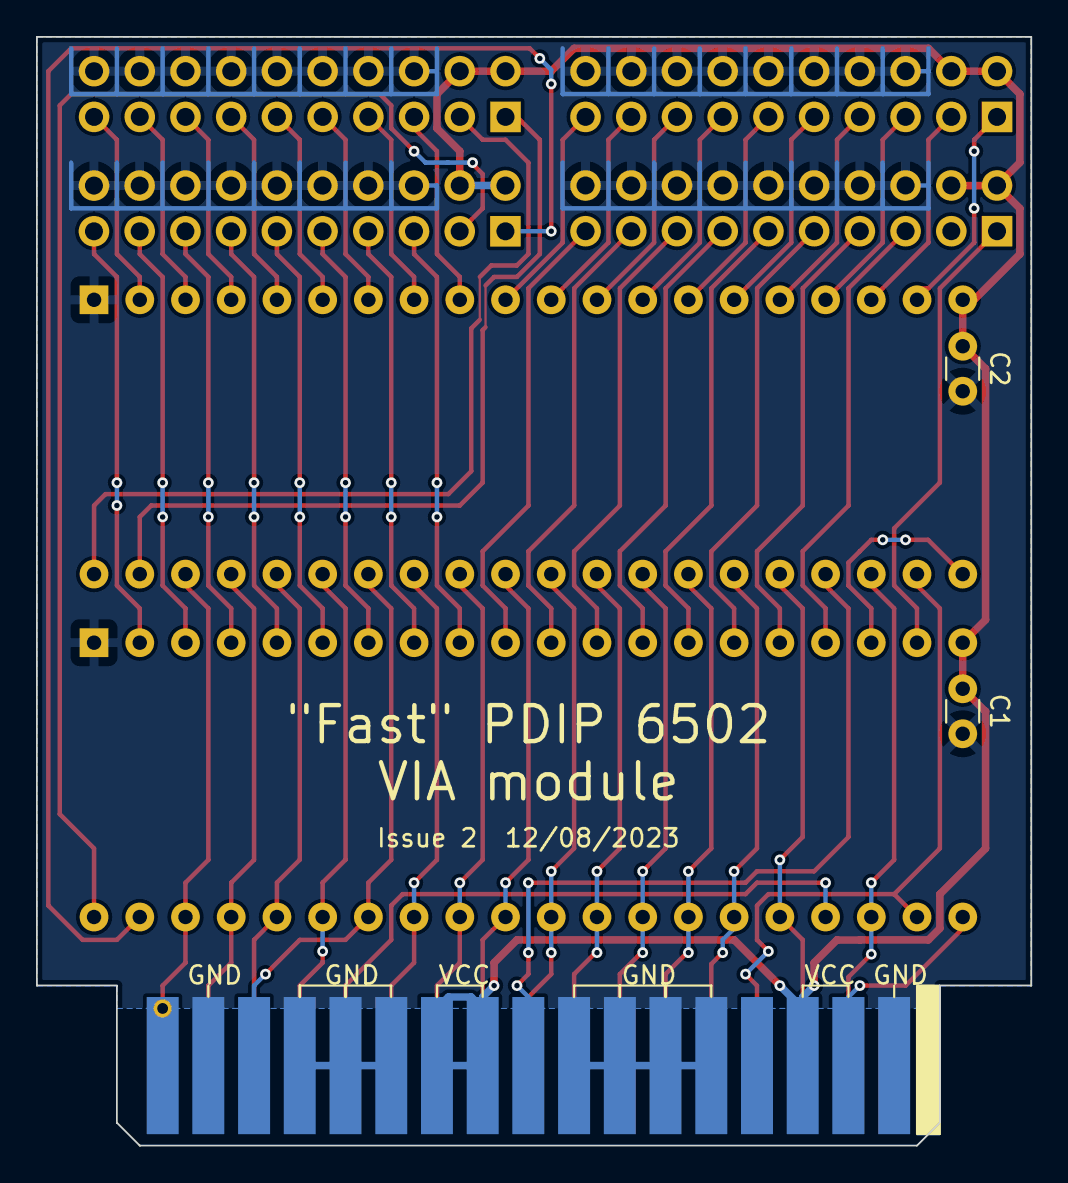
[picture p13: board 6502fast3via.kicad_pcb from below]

Board: 2 copper layers, 55.2 x 61.6 mm, 9 parts (2 on the bottom side), 61 nets.

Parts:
C1, C2: .1u; C_Disc_D3.0mm_W1.6mm_P2.50mm
J1: conn_pcb_edge_33pin_sense; 6502fast2_IO_PCBEdge
J2, J3, J4, J5: Conn_02x10_Odd_Even; PinHeader_2x10_P2.54mm_Vertical
U1, U2: WD65C22; DIP-40_W15.24mm_Socket

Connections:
/CA1: J2.3, U1.40 (CA1)
/CA2: J2.1, U1.39 (CA2)
/CB1: U1.18 (CB1), U2.21 (~IRQ)
/CB2: J3.1, U1.19 (CB2)
/CC1: J4.3, U2.40 (CA1)
/CC2: J4.1, U2.39 (CA2)
/CD1: J5.3, U2.18 (CB1)
/CD2: J5.1, U2.19 (CB2)
/PA0: J2.19, U1.2 (PA0)
/PA1: J2.17, U1.3 (PA1)
/PA2: J2.15, U1.4 (PA2)
/PA3: J2.13, U1.5 (PA3)
/PA4: J2.11, U1.6 (PA4)
/PA5: J2.9, U1.7 (PA5)
/PA6: J2.7, U1.8 (PA6)
/PA7: J2.5, U1.9 (PA7)
/PB0: J3.19, U1.10 (PB0)
/PB1: J3.17, U1.11 (PB1)
/PB2: J3.15, U1.12 (PB2)
/PB3: J3.13, U1.13 (PB3)
/PB4: J3.11, U1.14 (PB4)
/PB5: J3.9, U1.15 (PB5)
/PB6: J3.7, U1.16 (PB6)
/PB7: J3.5, U1.17 (PB7)
/PC0: J4.19, U2.2 (PA0)
/PC1: J4.17, U2.3 (PA1)
/PC2: J4.15, U2.4 (PA2)
/PC3: J4.13, U2.5 (PA3)
/PC4: J4.11, U2.6 (PA4)
/PC5: J4.9, U2.7 (PA5)
/PC6: J4.7, U2.8 (PA6)
/PC7: J4.5, U2.9 (PA7)
/PD0: J5.19, U2.10 (PB0)
/PD1: J5.17, U2.11 (PB1)
/PD2: J5.15, U2.12 (PB2)
/PD3: J5.13, U2.13 (PB3)
/PD4: J5.11, U2.14 (PB4)
/PD5: J5.9, U2.15 (PB5)
/PD6: J5.7, U2.16 (PB6)
/PD7: J5.5, U2.17 (PB7)
/VA0: J1.33, U1.38 (RS0), U2.38 (RS0)
/VA1: J1.32, U1.37 (RS1), U2.37 (RS1)
/VA2: J1.30, U1.36 (RS2), U2.36 (RS2)
/VA3: J1.28, U1.35 (RS3), U2.35 (RS3)
/VA7: J1.26, U1.24 (CS1)
/VCLK: J1.6, U1.25 (PHI2), U2.25 (PHI2)
/VD0: J1.24, U1.33 (D0), U2.33 (D0)
/VD1: J1.22, U1.32 (D1), U2.32 (D1)
/VD2: J1.20, U1.31 (D2), U2.31 (D2)
/VD3: J1.18, U1.30 (D3), U2.30 (D3)
/VD4: J1.16, U1.29 (D4), U2.29 (D4)
/VD5: J1.14, U1.28 (D5), U2.28 (D5)
/VD6: J1.12, U1.27 (D6), U2.27 (D6)
/VD7: J1.10, U1.26 (D7), U2.26 (D7)
/VR~W: J1.8, U1.22 (R/~W), U2.22 (R/~W)
/~VA7: J1.17, U2.24 (CS1)
/~VCS: J1.4, U1.23 (~CS2), U2.23 (~CS2)
/~VIRQ: J1.3, U1.21 (~IRQ)
/~VRESET: J1.29, U1.34 (~RESET), U2.34 (~RESET)
GND1: C1.2, C2.2, J1.1, J1.9, J1.11, J1.13, J1.15, J1.23, J1.25, J1.27, J1.31, J2.6, J2.8, J2.10, J2.12, J2.14, J2.16, J2.18, J2.20, J3.6, J3.8, J3.10, J3.12, J3.14, J3.16, J3.18, J3.20, J4.6, J4.8, J4.10, J4.12, J4.14, J4.16, J4.18, J4.20, J5.6, J5.8, J5.10, J5.12, J5.14, J5.16, J5.18, J5.20, U1.1 (GND), U2.1 (GND)
VCCQ: C1.1, C2.1, J1.5, J1.19, J1.21, J2.2, J2.4, J3.2, J3.4, J4.2, J4.4, J5.2, J5.4, U1.20 (VCC), U2.20 (VCC)

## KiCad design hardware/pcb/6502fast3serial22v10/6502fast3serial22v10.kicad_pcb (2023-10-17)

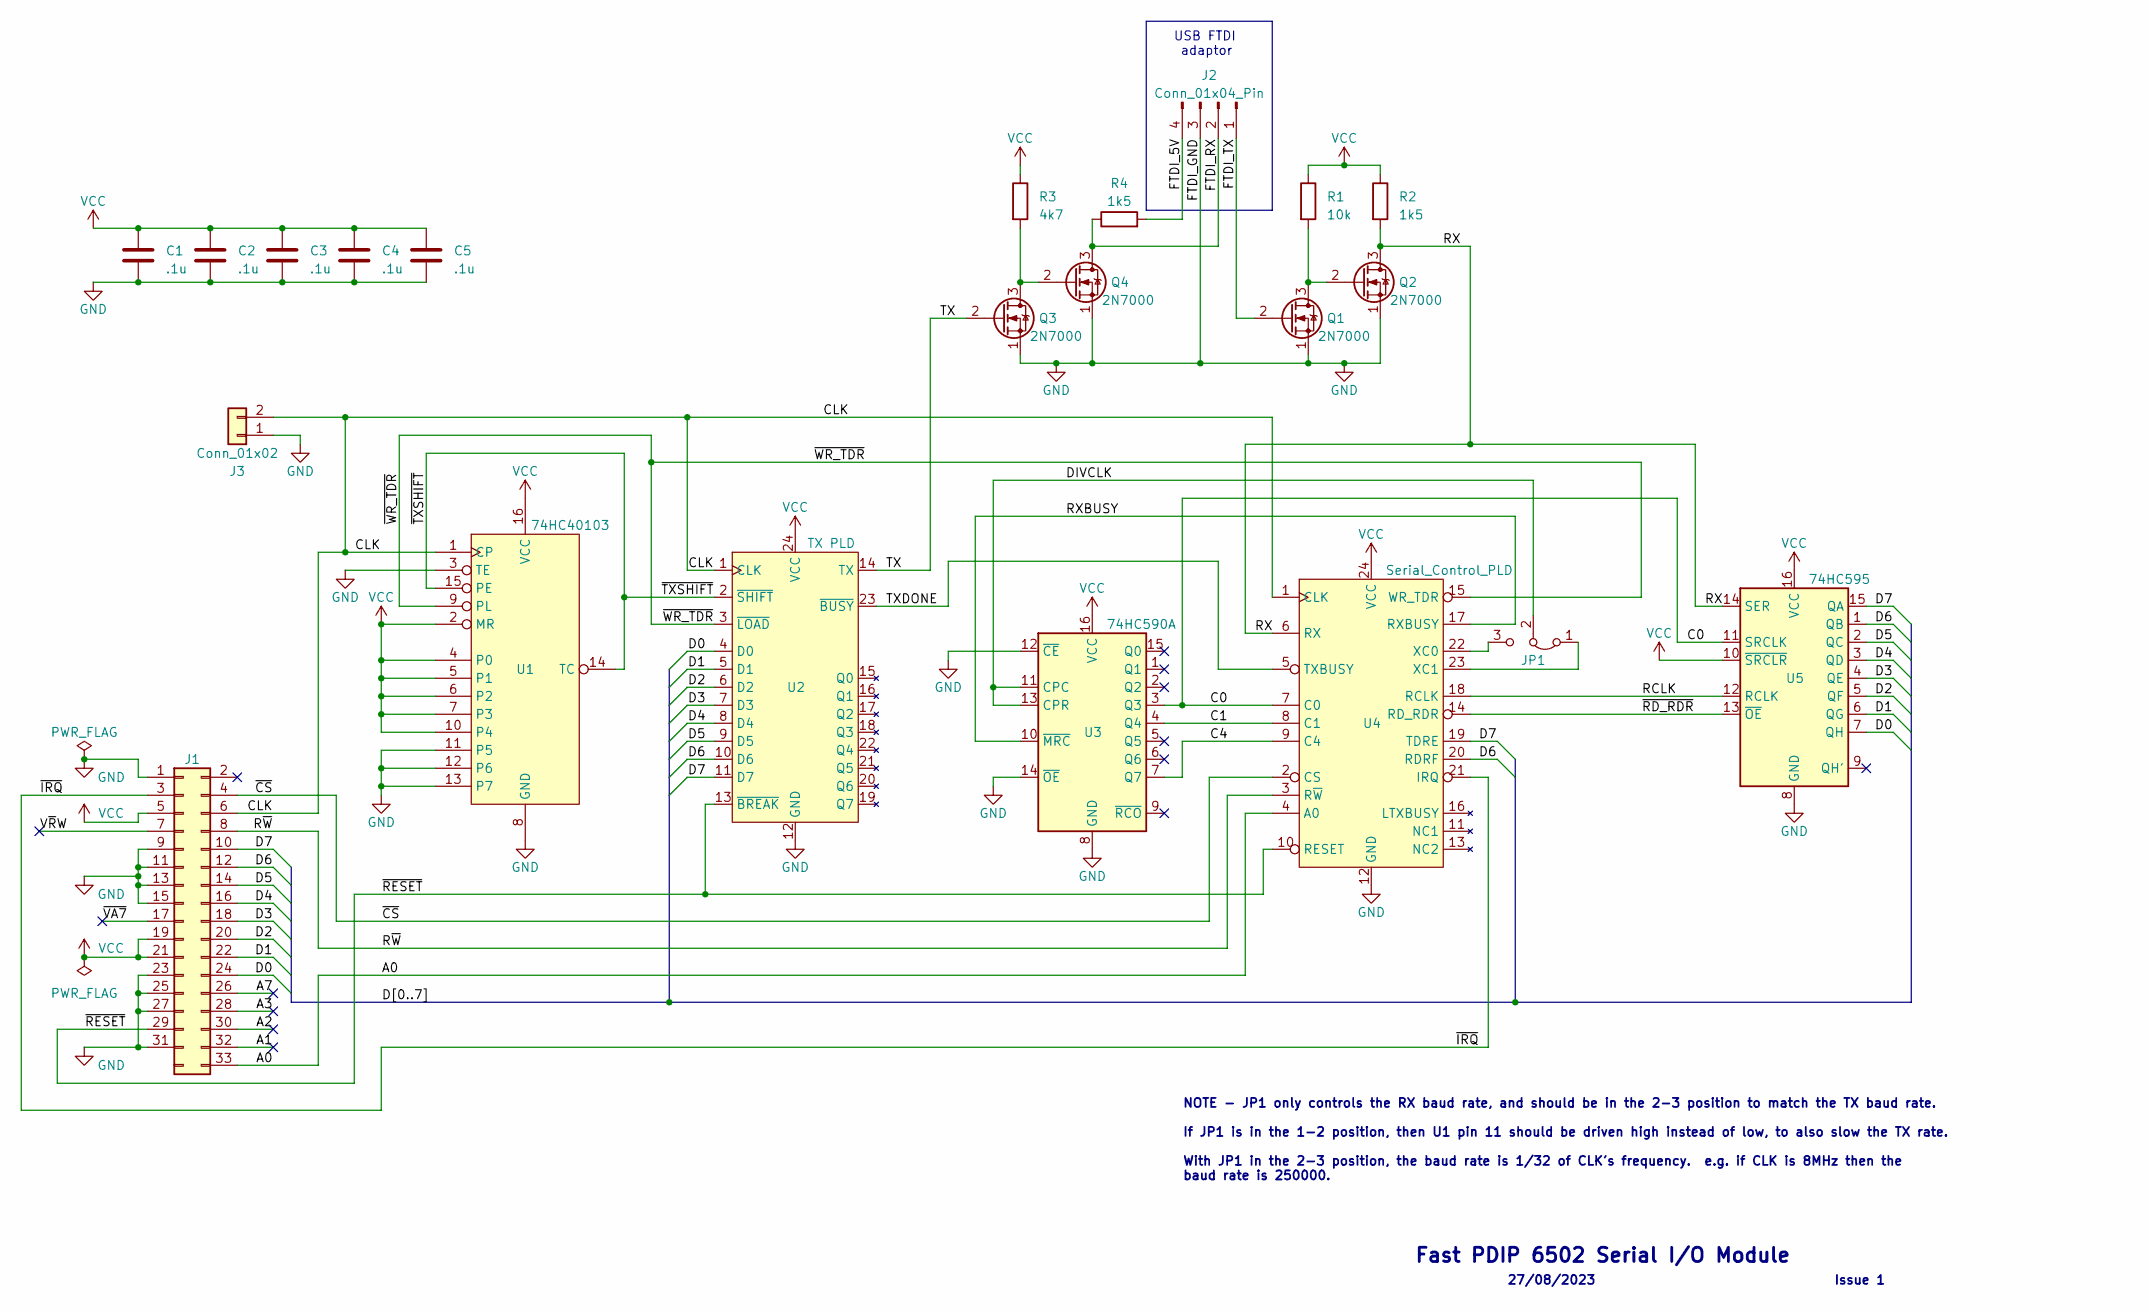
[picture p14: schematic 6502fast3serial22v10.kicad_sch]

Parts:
C1, C2, C3, C4, C5: .1u; C_Disc_D3.8mm_W2.6mm_P2.50mm
J1: conn_pcb_edge_33pin_sense; PCB_Edge_33pin_sense
J2: Conn_01x04_Pin; PinHeader_1x04_P2.54mm_Horizontal
J3: Conn_01x02; PinHeader_1x02_P2.54mm_Vertical
JP1: Jumper_3_Bridged12; PinHeader_1x03_P2.54mm_Horizontal
Q1, Q2, Q3, Q4: 2N7000; TO-92_Inline
R1: 10k; R_Axial_DIN0204_L3.6mm_D1.6mm_P7.62mm_Horizontal
R2, R4: 1k5; R_Axial_DIN0204_L3.6mm_D1.6mm_P7.62mm_Horizontal
R3: 4k7; R_Axial_DIN0204_L3.6mm_D1.6mm_P7.62mm_Horizontal
U1: 74HC40103; DIP-16_W7.62mm
U2: TX PLD; DIP-24_W7.62mm
U3: 74HC590A; DIP-16_W7.62mm
U4: Serial_Control_PLD; DIP-24_W7.62mm
U5: 74HC595; DIP-16_W7.62mm

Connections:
/A0: J1.33, U4.4 (A0)
/A1: J1.32
/A2: J1.30
/A3: J1.28
/A7: J1.26
/C0: U3.3 (Q3), U4.7 (C0), U5.11 (SRCLK)
/C1: U3.4 (Q4), U4.8 (C1)
/C4: U3.7 (Q7), U4.9 (C4)
/CLK: J1.6, J3.2, U1.1 (CP), U2.1 (CLK), U4.1 (CLK)
/D0: J1.24, U2.4 (D0), U5.7 (QH)
/D1: J1.22, U2.5 (D1), U5.6 (QG)
/D2: J1.20, U2.6 (D2), U5.5 (QF)
/D3: J1.18, U2.7 (D3), U5.4 (QE)
/D4: J1.16, U2.8 (D4), U5.3 (QD)
/D5: J1.14, U2.9 (D5), U5.2 (QC)
/D6: J1.12, U2.10 (D6), U4.20 (RDRF), U5.1 (QB)
/D7: J1.10, U2.11 (D7), U4.19 (TDRE), U5.15 (QA)
/DIVCLK: JP1.2 (C), U3.11 (CPC), U3.13 (CPR)
/FTDI_5V: J2.4, R4.2
/FTDI_RX: J2.2, Q4.3 (D), R4.1
/FTDI_TX: J2.1, Q1.2 (G)
/RCLK: U4.18 (RCLK), U5.12 (RCLK)
/RX: Q2.3 (D), R2.2, U4.6 (RX), U5.14 (SER)
/RXBUSY: U3.10 (~MRC), U4.17 (RXBUSY)
/R~W: J1.8, U4.3 (R~W)
/TX: Q3.2 (G), U2.14 (TX)
/TXDONE: U2.23 (~BUSY), U4.5 (TXBUSY)
/V~RW: J1.7
/~CS: J1.4, U4.2 (CS)
/~IRQ: J1.3, U4.21 (IRQ)
/~RD_RDR: U4.14 (RD_RDR), U5.13 (~OE)
/~RESET: J1.29, U2.13 (~BREAK), U4.10 (RESET)
/~TXSHIFT: U1.14 (TC), U1.15 (PE), U2.2 (~SHIFT)
/~VA7: J1.17
/~WR_TDR: U1.9 (PL), U2.3 (~LOAD), U4.15 (WR_TDR)
GND: C1.2, C2.2, C3.2, C4.2, C5.2, J1.1, J1.9, J1.11, J1.13, J1.15, J1.23, J1.25, J1.27, J1.31, J2.3, J3.1, Q1.1 (S), Q2.1 (S), Q3.1 (S), Q4.1 (S), U1.3 (TE), U1.8 (GND), U1.11 (P5), U1.12 (P6), U1.13 (P7), U2.12 (GND), U3.8 (GND), U3.12 (~CE), U3.14 (~OE), U4.12 (GND), U5.8 (GND)
unnamed: JP1.1 (A), U4.23 (XC1)
unnamed: JP1.3 (B), U4.22 (XC0)
unnamed: Q1.3 (D), Q2.2 (G), R1.2
unnamed: Q3.3 (D), Q4.2 (G), R3.2
VCC: C1.1, C2.1, C3.1, C4.1, C5.1, J1.5, J1.19, J1.21, R1.1, R2.1, R3.1, U1.2 (MR), U1.4 (P0), U1.5 (P1), U1.6 (P2), U1.7 (P3), U1.10 (P4), U1.16 (VCC), U2.24 (VCC), U3.16 (VCC), U4.24 (VCC), U5.10 (~SRCLR), U5.16 (VCC)

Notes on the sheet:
NOTE - JP1 only controls the RX baud rate, and should be in the 2-3 position to match the TX baud rate. If JP1 is in the 1-2 position, then U1 pin 11 should be driven high instead of low, to also slow the TX rate. With JP1 in the 2-3 position, the baud rate is 1/32 of CLK's frequency. e.g. if CLK i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
USB FTDI adaptor
27/08/2023
Fast PDIP 6502 Serial I/O Module
Issue 1

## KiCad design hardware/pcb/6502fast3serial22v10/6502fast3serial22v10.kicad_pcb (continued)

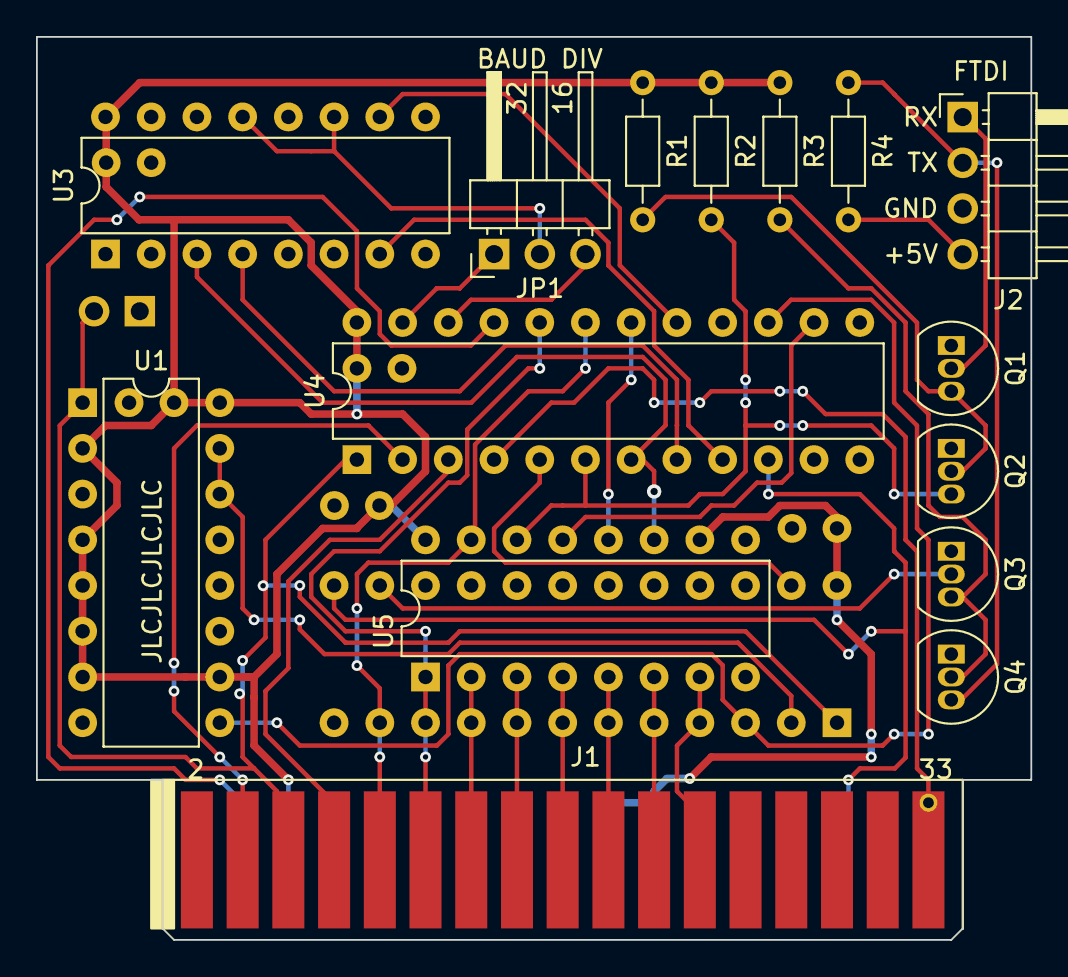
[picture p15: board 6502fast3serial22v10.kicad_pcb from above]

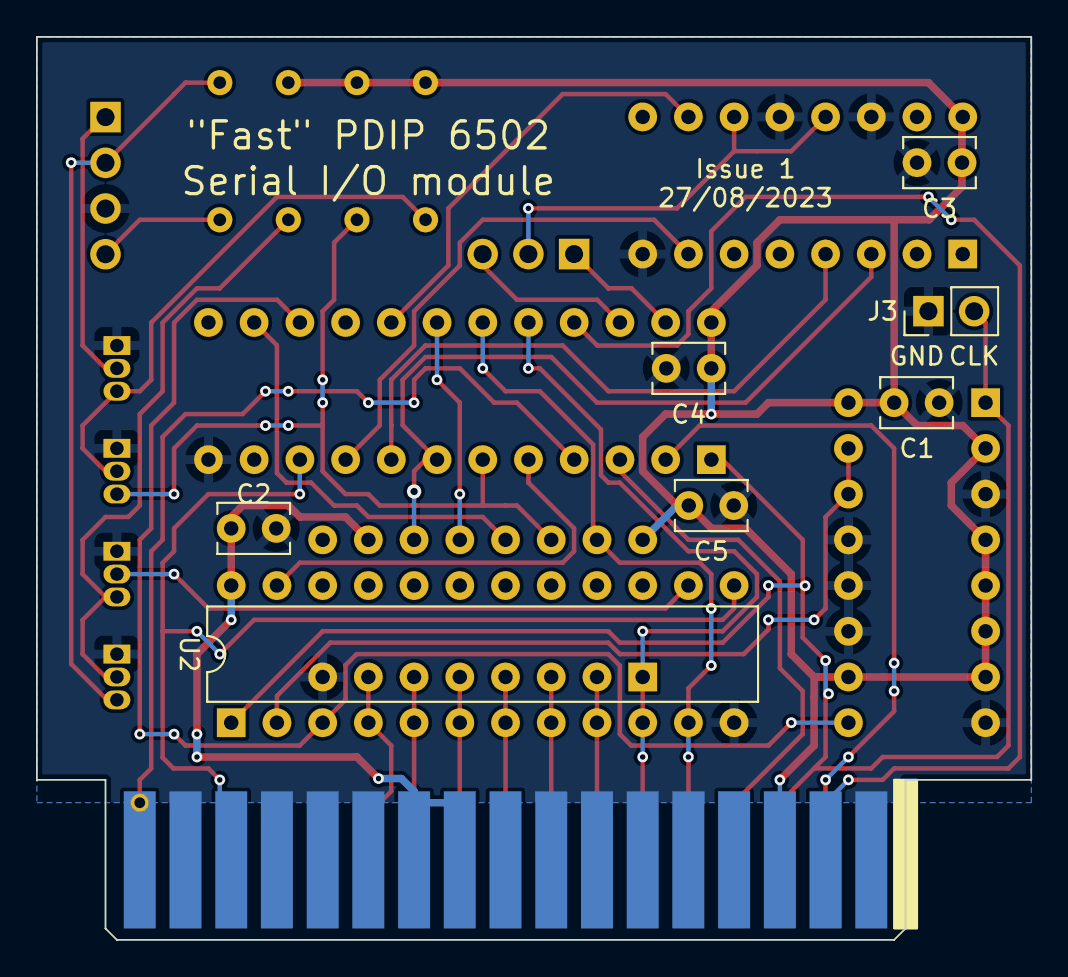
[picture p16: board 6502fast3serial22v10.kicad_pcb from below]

Board: 2 copper layers, 55.2 x 50.2 mm, 22 parts (7 on the bottom side), 35 nets.

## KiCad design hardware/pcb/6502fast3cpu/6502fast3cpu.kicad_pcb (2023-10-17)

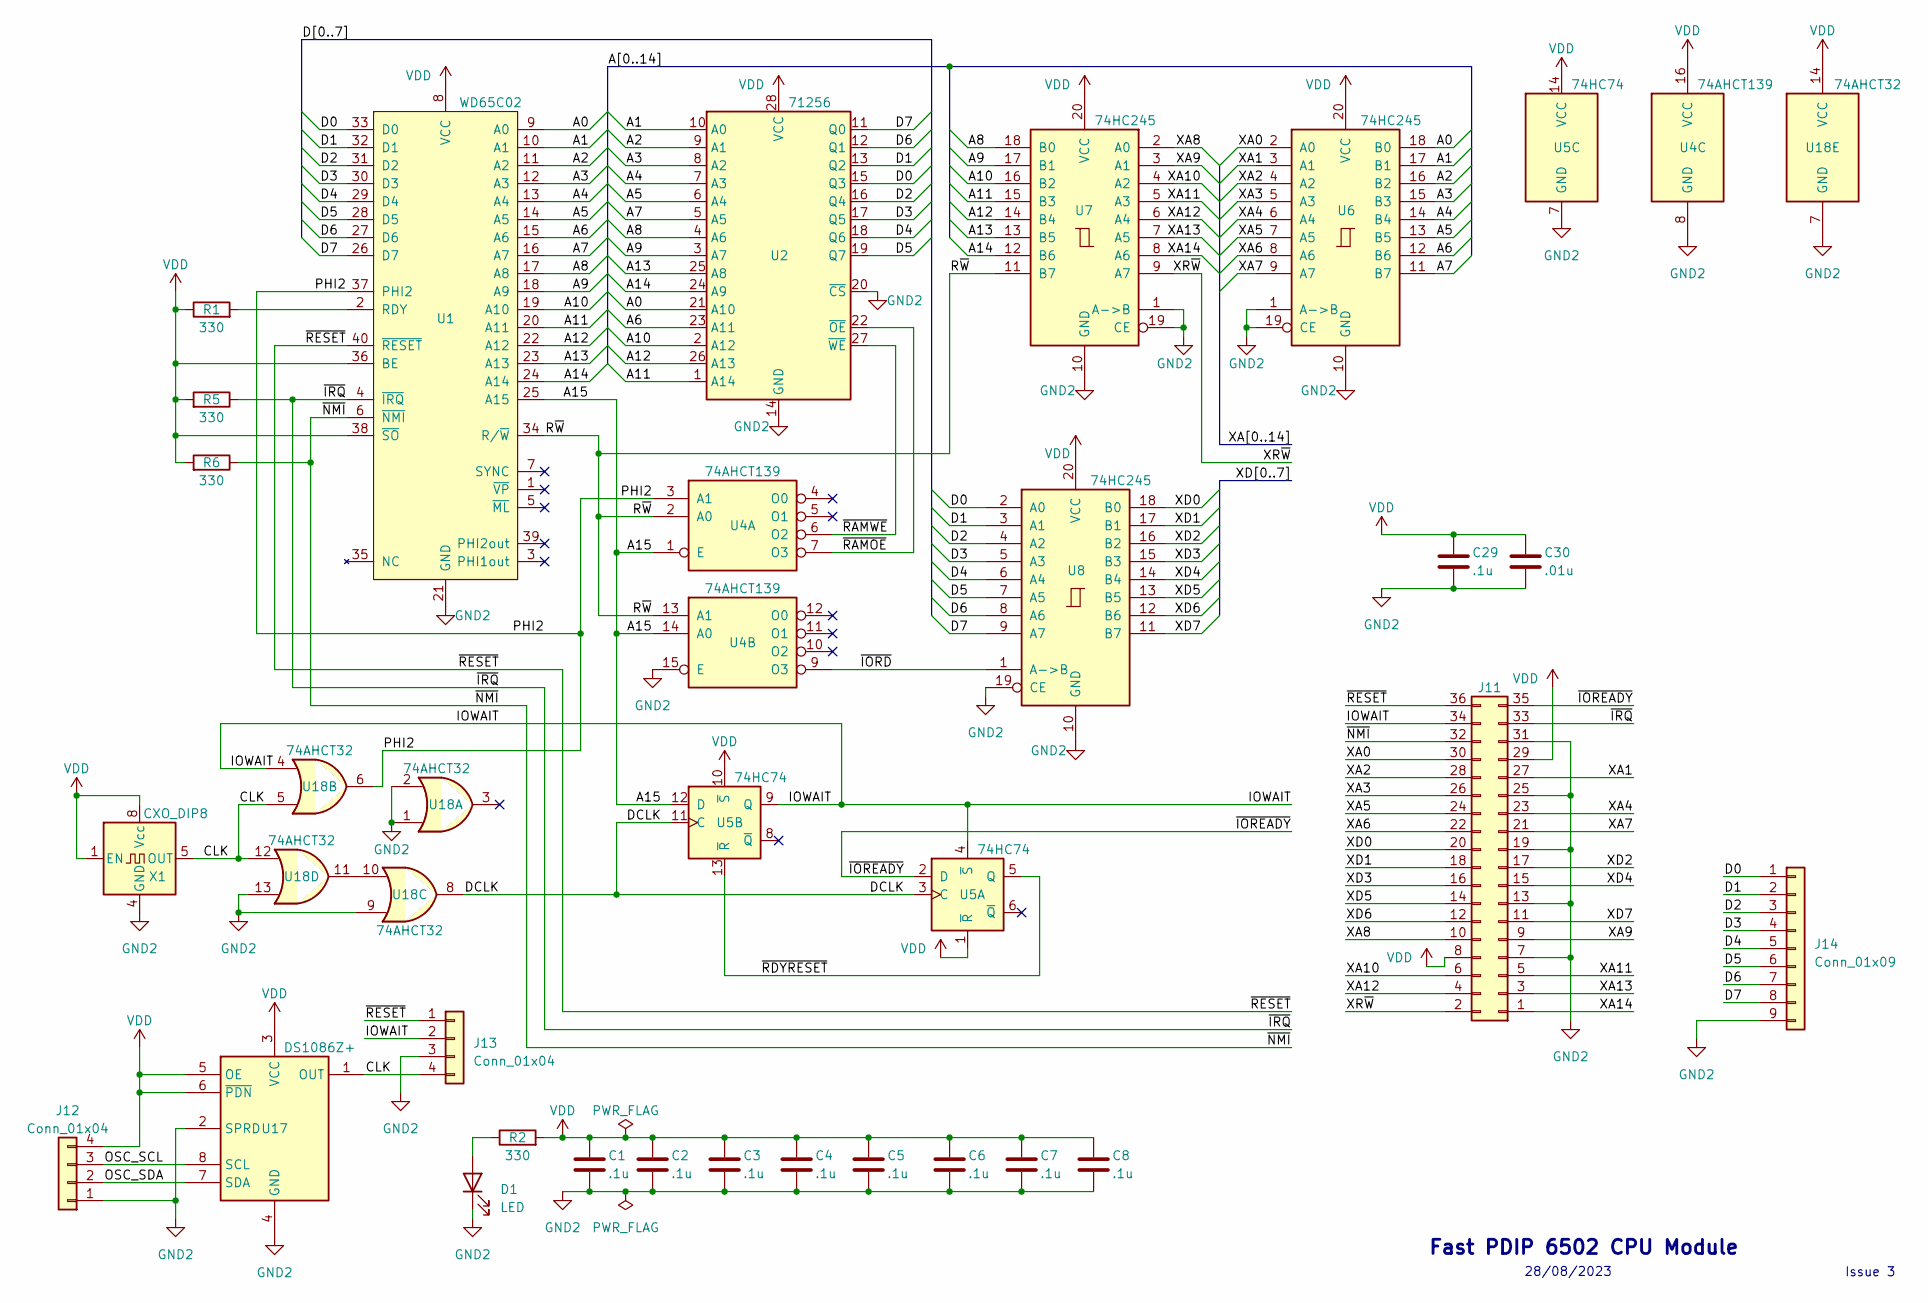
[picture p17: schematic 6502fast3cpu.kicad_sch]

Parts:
C1, C2, C3, C4, C5, C6, C7, C8: .1u; C_Disc_D3.0mm_W1.6mm_P2.50mm
C29: .1u; C_0603_1608Metric
C30: .01u; C_0603_1608Metric
D1: LED; LED_D5.0mm_Horizontal_O1.27mm_Z3.0mm
J11: Conn_02x18_Odd_Even; PCB_Edge_36pin
J12: Conn_01x04; PinHeader_1x04_P2.54mm_Vertical
J13: Conn_01x04; PinHeader_1x04_P2.54mm_Horizontal
J14: Conn_01x09; PinHeader_1x09_P2.54mm_Vertical
R1, R2, R5, R6: 330; R_Axial_DIN0204_L3.6mm_D1.6mm_P7.62mm_Horizontal
U1: WD65C02; DIP-40_W15.24mm_Socket
U2: 71256; DIP-28_W7.62mm
U4: 74AHCT139; DIP-16_W7.62mm
U5: 74HC74; DIP-14_W7.62mm
U6, U7, U8: 74HC245; DIP-20_W7.62mm
U17: DS1086Z+; SOIC127P600X175-8N; Mouser Part Number 700-DS1086Z
U18: 74AHCT32; DIP-14_W7.62mm
X1: CXO_DIP8; DIP-8_W7.62mm_Socket

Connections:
/A0: U1.9 (A0), U2.21 (A10), U6.18 (B0)
/A1: U1.10 (A1), U2.10 (A0), U6.17 (B1)
/A2: U1.11 (A2), U2.9 (A1), U6.16 (B2)
/A3: U1.12 (A3), U2.8 (A2), U6.15 (B3)
/A4: U1.13 (A4), U2.7 (A3), U6.14 (B4)
/A5: U1.14 (A5), U2.6 (A4), U6.13 (B5)
/A6: U1.15 (A6), U2.23 (A11), U6.12 (B6)
/A7: U1.16 (A7), U2.5 (A5), U6.11 (B7)
/A8: U1.17 (A8), U2.4 (A6), U7.18 (B0)
/A9: U1.18 (A9), U2.3 (A7), U7.17 (B1)
/A10: U1.19 (A10), U2.2 (A12), U7.16 (B2)
/A11: U1.20 (A11), U2.1 (A14), U7.15 (B3)
/A12: U1.22 (A12), U2.26 (A13), U7.14 (B4)
/A13: U1.23 (A13), U2.25 (A8), U7.13 (B5)
/A14: U1.24 (A14), U2.24 (A9), U7.12 (B6)
/A15: U1.25 (A15), U4.1 (E), U4.14 (A0), U5.12 (D)
/CLK: J13.4, U17.1 (OUT), U18.5, U18.12, X1.5 (OUT)
/D0: J14.1, U1.33 (D0), U2.15 (Q3), U8.2 (A0)
/D1: J14.2, U1.32 (D1), U2.13 (Q2), U8.3 (A1)
/D2: J14.3, U1.31 (D2), U2.16 (Q4), U8.4 (A2)
/D3: J14.4, U1.30 (D3), U2.17 (Q5), U8.5 (A3)
/D4: J14.5, U1.29 (D4), U2.18 (Q6), U8.6 (A4)
/D5: J14.6, U1.28 (D5), U2.19 (Q7), U8.7 (A5)
/D6: J14.7, U1.27 (D6), U2.12 (Q1), U8.8 (A6)
/D7: J14.8, U1.26 (D7), U2.11 (Q0), U8.9 (A7)
/DCLK: U5.3 (C), U5.11 (C), U18.8
/IOWAIT: J11.34, J13.2, U5.4 (~S), U5.9 (Q), U18.4
/OSC_SCL: J12.3, U17.8 (SCL)
/OSC_SDA: J12.2, U17.7 (SDA)
/PHI2: U1.37 (PHI2), U4.3 (A1), U18.6
/R~W: U1.34 (R/~W), U4.2 (A0), U4.13 (A1), U7.11 (B7)
/XA0: J11.30, U6.2 (A0)
/XA1: J11.27, U6.3 (A1)
/XA2: J11.28, U6.4 (A2)
/XA3: J11.26, U6.5 (A3)
/XA4: J11.23, U6.6 (A4)
/XA5: J11.24, U6.7 (A5)
/XA6: J11.22, U6.8 (A6)
/XA7: J11.21, U6.9 (A7)
/XA8: J11.10, U7.2 (A0)
/XA9: J11.9, U7.3 (A1)
/XA10: J11.6, U7.4 (A2)
/XA11: J11.5, U7.5 (A3)
/XA12: J11.4, U7.6 (A4)
/XA13: J11.3, U7.7 (A5)
/XA14: J11.1, U7.8 (A6)
/XD0: J11.20, U8.18 (B0)
/XD1: J11.18, U8.17 (B1)
/XD2: J11.17, U8.16 (B2)
/XD3: J11.16, U8.15 (B3)
/XD4: J11.15, U8.14 (B4)
/XD5: J11.14, U8.13 (B5)
/XD6: J11.12, U8.12 (B6)
/XD7: J11.11, U8.11 (B7)
/XR~W: J11.2, U7.9 (A7)
/~IORD: U4.9 (O3), U8.1 (A->B)
/~IOREADY: J11.35, U5.2 (D)
/~IRQ: J11.33, R5.1, U1.4 (~IRQ)
/~NMI: J11.32, R6.1, U1.6 (~NMI)
/~RAMOE: U2.22 (~OE), U4.7 (O3)
/~RAMWE: U2.27 (~WE), U4.6 (O2)
/~RDYRESET: U5.5 (Q), U5.13 (~R)
/~RESET: J11.36, J13.1, U1.40 (~RESET)
GND2: C1.2, C2.2, C3.2, C4.2, C5.2, C6.2, C7.2, C8.2, C29.2, C30.2, D1.1 (K), J11.7, J11.13, J11.19, J11.25, J11.31, J12.1, J13.3, J14.9, U1.21 (GND), U2.14 (GND), U2.20 (~CS), U4.8 (GND), U4.15 (E), U5.7 (GND), U6.1 (A->B), U6.10 (GND), U6.19 (CE), U7.1 (A->B), U7.10 (GND), U7.19 (CE), U8.10 (GND), U8.19 (CE), U17.2 (SPRD), U17.4 (GND), U18.1, U18.2, U18.7 (GND), U18.9, U18.13, X1.4 (GND)
unnamed: D1.2 (A), R2.1
unnamed: R1.2, U1.2 (RDY)
unnamed: U18.10, U18.11
VDD: C1.1, C2.1, C3.1, C4.1, C5.1, C6.1, C7.1, C8.1, C29.1, C30.1, J11.8, J11.29, J12.4, R1.1, R2.2, R5.2, R6.2, U1.8 (VCC), U1.36 (BE), U1.38 (~SO), U2.28 (VCC), U4.16 (VCC), U5.1 (~R), U5.10 (~S), U5.14 (VCC), U6.20 (VCC), U7.20 (VCC), U8.20 (VCC), U17.3 (VCC), U17.5 (OE), U17.6 (~PDN), U18.14 (VCC), X1.1 (EN), X1.8 (Vcc)

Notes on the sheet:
Issue 3
Fast PDIP 6502 CPU Module
28/08/2023

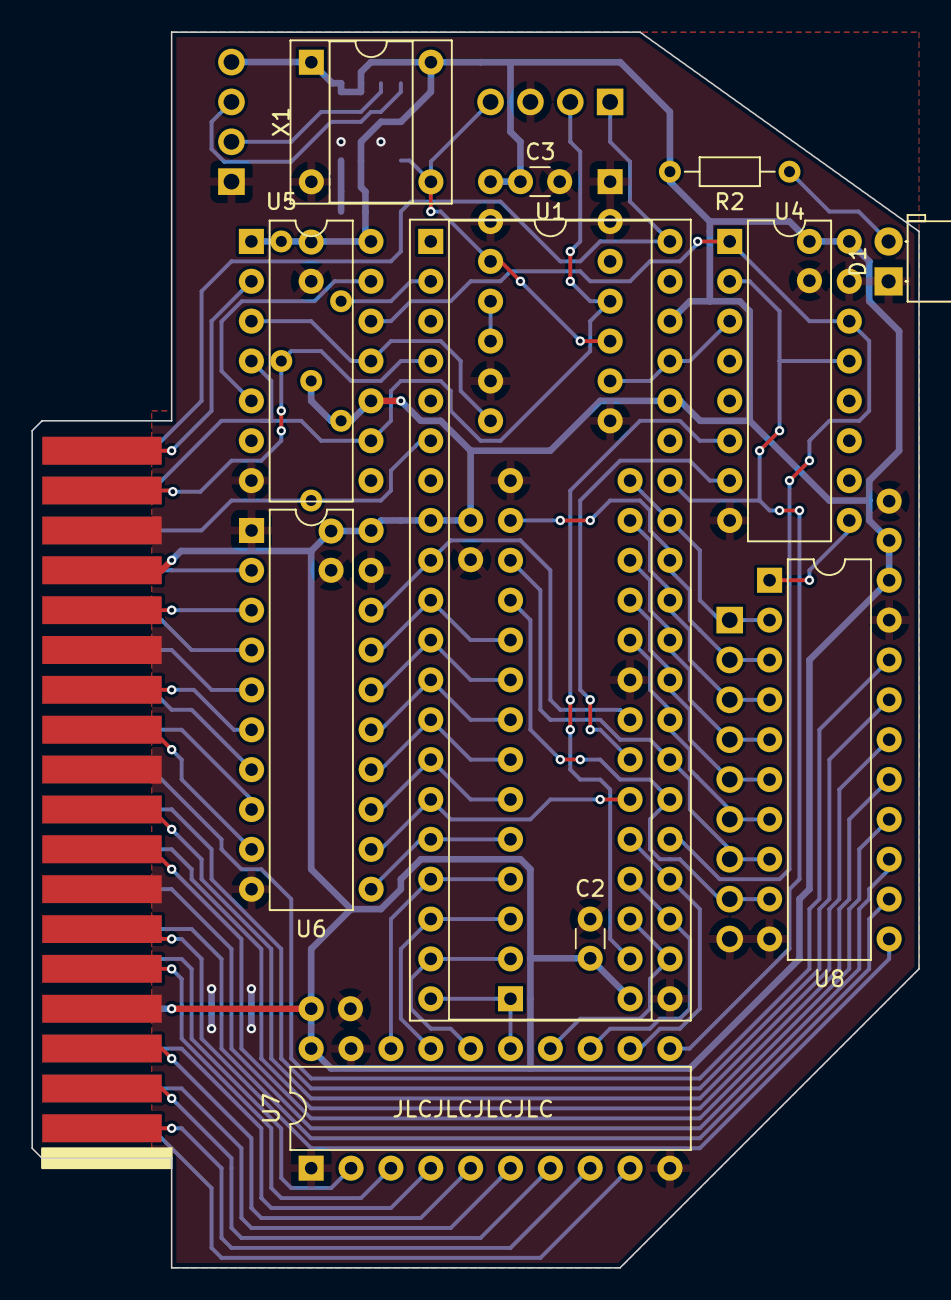
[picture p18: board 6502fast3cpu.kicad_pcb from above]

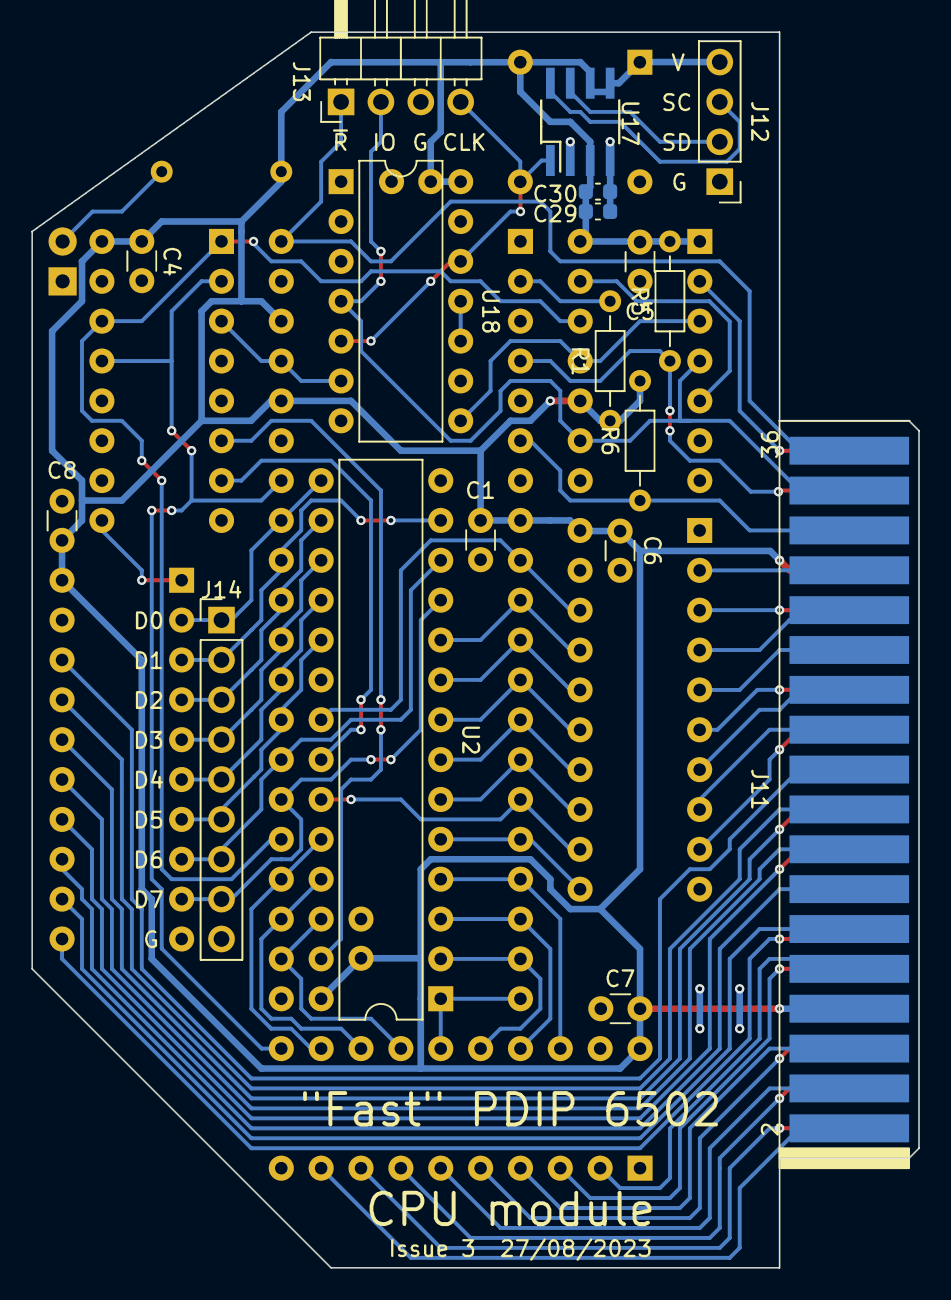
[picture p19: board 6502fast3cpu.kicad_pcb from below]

Board: 2 copper layers, 56.5 x 78.7 mm, 29 parts (18 on the bottom side), 68 nets.

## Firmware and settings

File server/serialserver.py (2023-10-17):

import select
import serial
import sys
import termios
import time
import tty


BAUD = 250000

LOGLEVEL = 1


def log(level, *args):
	if level <= LOGLEVEL:
		print(*args)



def adc(a, b, carry):
	r = a + b + carry
	return r % 256, r // 256



def cmd_start(cmd):
	log(3, "cmd_start(%d)" % cmd)
	ser.write(bytes([cmd]))
	echo = ser.read(1)[0]
	if echo != cmd:
		print("Echo mismatch - cmd=%s echo=%s" % (cmd, echo))
		sys.exit(1)


def cmd_address(addr):
	log(2, "cmd_address(%04x)" % addr)
	cmd_start(1)
	payload = bytes([addr % 256, addr // 256])
	ser.write(payload)
	echo = ser.read(2)
	if echo != payload:
		print("Echo mismatch - address command - payload=%s echo=%s" % (repr(payload), repr(echo)))
		sys.exit(1)


def cmd_loaddata(data):
	log(2, "cmd_loaddata")
	cmd_start(2)
	payload = bytes(data)
	log(4, "data: %s" % repr(payload))
	ser.write(payload)
	echo = ser.read(2)

	check2 = 0
	check3 = 0
	carry = 0
	for b in payload:
		check2, carry = adc(b, check2, carry)
		check3, carry = adc(check2, check3, carry)

	expected_echo = bytes([check2, check3])
	if echo != expected_echo:	
		print("Echo mismatch - loaddata command - expected=%s echo=%s" % (repr(expected_echo), repr(echo)))
		sys.exit(1)

def cmd_execute():
	log(2, "cmd_execute()")
	cmd_start(3)



def load_file(address, filename):
	log(1, "Reading file '%s'" % filename)
	with open(filename, "rb") as fp:
		data = fp.read()
		fp.close()

	log(1, "Loading %04x bytes to address %04x" % (len(data), address))
	cmd_address(address)
	for i in range(0, len(data), 256):
		block = data[i:i+256]
		if len(block) < 256:
			block = block + bytes(256-len(block))
		cmd_loaddata(block)


def go(address):
	log(1, "Go to %04x" % address)
	cmd_address(address)
	cmd_execute()


def serialconsole():
	log(1, "\n--- Serial console, ^C to quit ---\n")

	outfile = open("log.txt", "w")

	stdin = sys.stdin.fileno()
	tattr = termios.tcgetattr(stdin)
	ser.timeout = 0

	try:
		tty.setcbreak(stdin, termios.TCSANOW)

		while True:
			readyinputs = select.select([sys.stdin, ser], [], [], 1000)[0]
			if sys.stdin in readyinputs:
				b = sys.stdin.buffer.read(1)
				ser.write(b)
			if ser in readyinputs:
				buffer = ser.read()
				if buffer:
					for b in buffer:
						if b < 128:
							print(chr(b), end="", flush=True)
							outfile.write(chr(b))
						else:
							print("\\x%02x" % b, end="", flush=True)
							outfile.write("\\x%02x" % b)

	finally:
		termios.tcsetattr(stdin, termios.TCSANOW, tattr)

	outfile.close()


log(1, "Initialising link")
ser = serial.Serial("/dev/ttyUSB0", BAUD, 8, "N", 1)

time.sleep(0.1)
ser.write(bytes([0xff]))

log(1, "Waiting for client")
buffer = b""
while True:
	buffer = buffer+ser.read()
	log(2, "input buffer: %s" % repr(buffer))
	if buffer.endswith(b"boot0001"):
		break
	if len(buffer) > 10:
		buffer = buffer[-10:]

log(1, "Connected at %d baud" % BAUD)
log(1, "")


apps = [
	( 0x0200, 0x0206, "boottestcode" ),
	( 0x0700, 0x0700, "osapp" ),
	( 0x0200, 0x020c, "dormann" ),
	( 0x0200, 0x0206, "memtest" ),
	( 0x0200, 0x0206, "sdtest" ),
	( 0x0200, 0x0206, "viatest" ),
	( 0x0200, 0x0206, "cpuspeed" ),
	( 0x7000, 0x7000, "gibl" ),
	( 0x0200, 0x0206, "mandel" ),
	( 0x0200, 0x0206, "mandel2" ),
	( 0x0200, 0x0206, "mandelcolour" ),
	( 0x0200, 0x0203, "primesieve" ),
	( 0x0200, 0x0203, "primesieveverbose" ),
	( 0x0200, 0x0203, "primesieve2" ),
	( 0x0200, 0x0203, "life" ),
]

while True:
	print("Choose code to run:")
	for i, (load,execute,name) in enumerate(apps):
		print(i, name)
	j = int(input('?'))
	if j < len(apps):
		break

load, execute, name = apps[j]
load_file(load, "../bin/apps/%s.bin" % name)
go(execute)


serialconsole()

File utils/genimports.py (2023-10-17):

import re
import sys

# Convert xa's "labels" file into a set of definitions that can be included
# in other assemblies

exp = re.compile(r"^([^,]*), *0x([0-9a-f]*), *([0-9]*),.*")

def loadsyms(filename):
	with open(filename) as f:
		syms = {}
		for line in f.readlines():
			m = exp.match(line)
			assert m
			sym,value,ns = m.groups()
			if ns == "0":
				if sym not in syms:
					syms[sym] = value
				else:
					syms[sym] = None
		f.close()
	remove = set()
	for sym,value in syms.items():
		if value is None:
			remove.add(sym)
	for sym in remove:
		del syms[sym]
	return syms


if __name__ == "__main__":
	infile = sys.argv[1]
	outfile = sys.argv[2]

	syms = loadsyms(infile)

	lines = ["%s = $%s\n" % (sym,syms[sym]) for sym in sorted(syms.keys())]

	with open(outfile, "w") as of:
		of.writelines(lines)
		of.close()
